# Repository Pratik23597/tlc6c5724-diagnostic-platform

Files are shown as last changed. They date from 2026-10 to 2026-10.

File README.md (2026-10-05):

# Portable Automotive RGB Lighting Diagnostic Platform

**Development and Validation of a Portable Automotive RGB Lighting Diagnostic Platform Using the TLC6C5724-Q1 Automotive LED Driver with Local Control and MQTT-Based Remote Monitoring through Node-RED**

University project, OTH Regensburg (2026) - Pratik Sukare

An ESP32-based test and control unit for the Texas Instruments **TLC6C5724-Q1**, a 24-channel constant-current RGB LED driver for automotive lighting. The platform drives all 24 outputs, runs the driver's built-in diagnostics, and reports faults both on a local TFT display and on a remote Node-RED dashboard over MQTT.

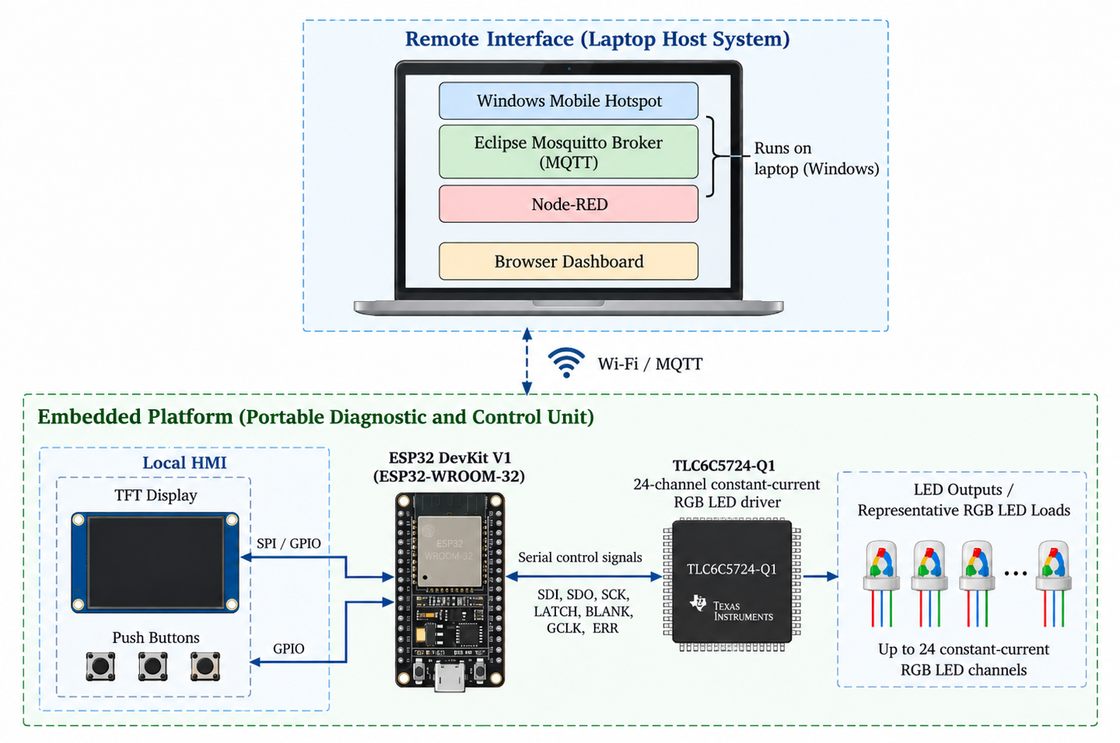
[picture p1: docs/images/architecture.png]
System architecture


## Features

- **Driver interface:** SPI-based serial control of the TLC6C5724-Q1 with separate LATCH, GCLK/BLANK PWM timing and the ERR fault line
- **Diagnostics:** LED open/short (LOD/LSD), short-to-ground, adjacent-pin short (APS), IREF open/short, thermal warning and over-temperature, LOD/LSD self-test, NEG/GCLK integrity test, device status, raw SID readout, error clear
- **Validated under controlled fault conditions:** open and shorted LEDs, short-to-ground, adjacent-pin shorts and IREF faults are detected as expected
- **Non-blocking firmware:** no long delays in the main loop; MQTT commands are queued as pending commands and executed by the main loop; automatic LED tests run as a state machine
- **Six automatic LED tests:** RGB colour cycle, RGB phase rotation, sequential chase, brightness sweep, all white, all off
- **Local HMI:** 128x160 SPI colour TFT and three push buttons - works without any network
- **Remote monitoring:** Eclipse Mosquitto + Node-RED Dashboard 2 with a diagnostics page and a per-channel LED control page (grayscale, dot correction)
- **Network recovery:** retries saved Wi-Fi profiles, and returns to the preferred hotspot if the MQTT broker is unreachable

| Prototype | Node-RED diagnostics |
|---|---|
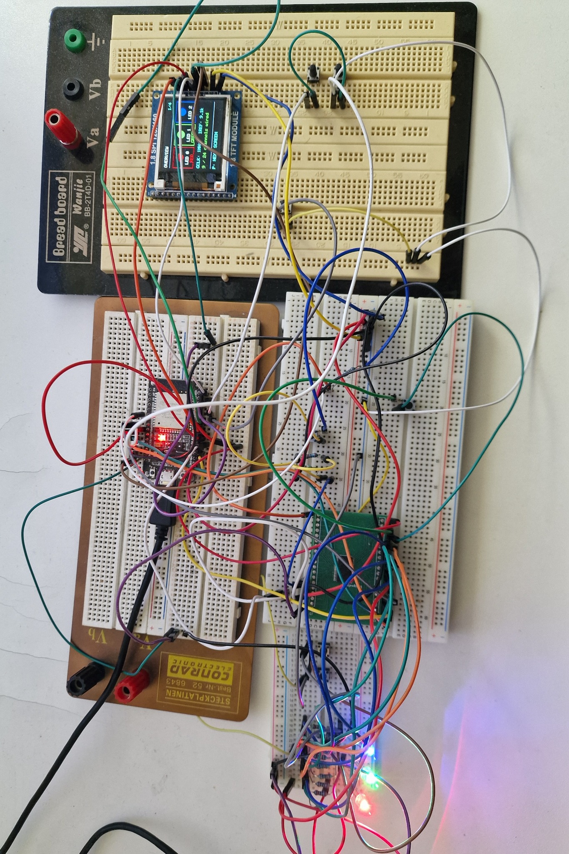
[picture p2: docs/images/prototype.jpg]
Prototype
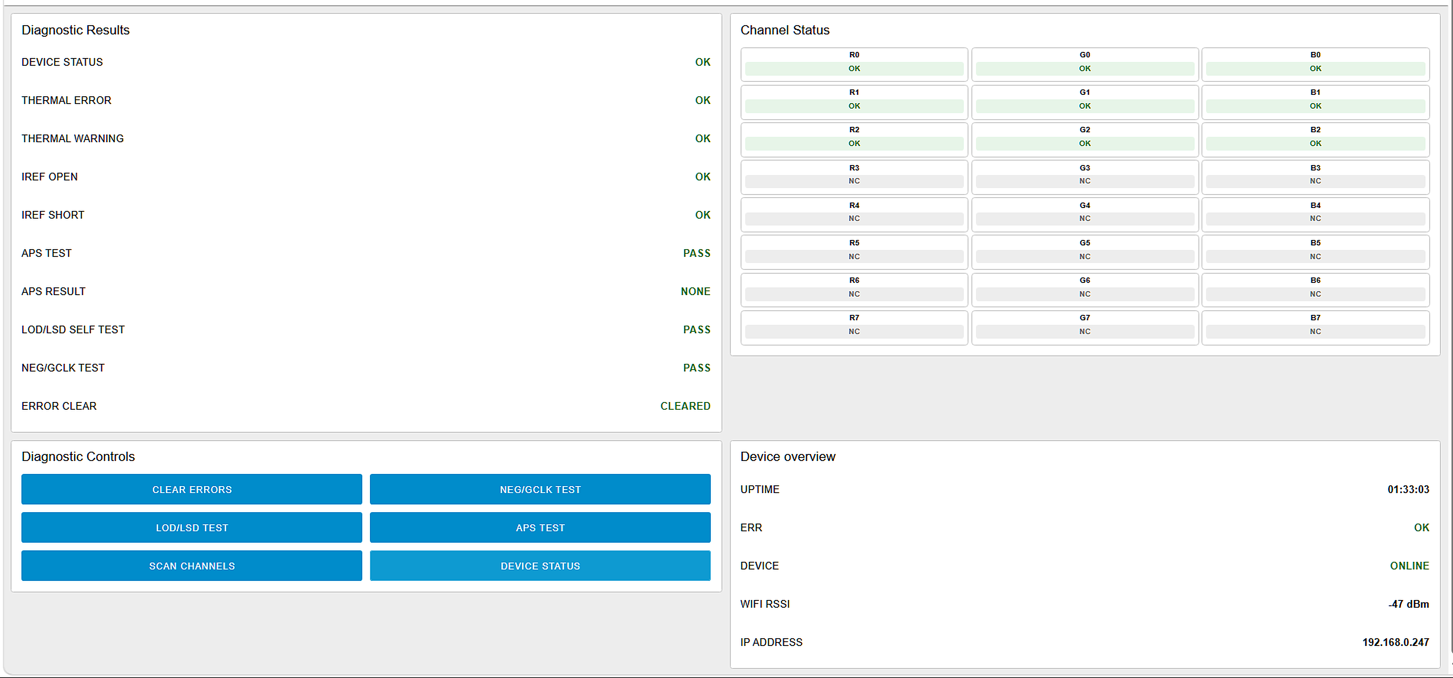
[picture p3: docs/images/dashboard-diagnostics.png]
Diagnostics dashboard
|  |  |

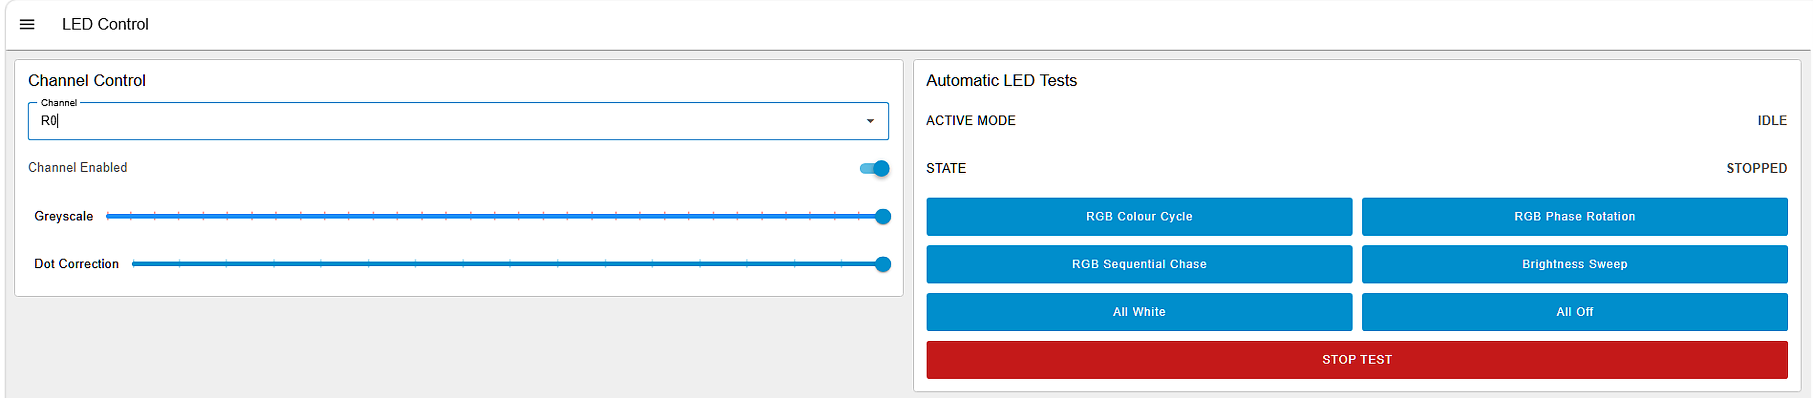
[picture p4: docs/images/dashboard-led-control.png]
LED control page


## Reports

- [Project report](reports/Project_Report.pdf) - design, implementation and results
- [Diagnostic validation report](reports/Diagnostic_Validation_Report.pdf) - test method, fault-injection steps and recorded results for every diagnostic

## Repository layout

| Path | Contents |
|---|---|
| `firmware/TLC6C5724_Diagnostic_Controller/` | ESP32 Arduino sketch, split by module (see below) |
| `node-red/flows.json` | Node-RED Dashboard 2 flow (import via *Menu > Import*) |
| `hardware/` | KiCad schematics (plus a PDF export) of the prototype, and the TLC breakout schematic and PCB layout |
| `mosquitto/` | Mosquitto demo config and a Windows launcher that starts Mosquitto and Node-RED and opens the dashboard |
| `docs/images/` | Architecture, prototype and dashboard figures |
| `reports/` | Project report (paper) and diagnostic validation report with test procedures and results |

Firmware modules:

- `TLC6C5724_Diagnostic_Controller.ino` - declarations and setup / main loop
- `TlcDriver.ino` - TLC frame building, serial transfer, GS/DC/BC configuration
- `Diagnostics.ino` - channel diagnostics, APS, IREF/device status, LOD/LSD, NEG/GCLK, SID debug
- `AutoTests.ino` - automatic RGB / phase / chase / brightness / static tests
- `NetworkMqtt.ino` - Wi-Fi profiles, MQTT commands, status publishing, recovery
- `DisplayUi.ino` - TFT pages and menu navigation
- `Buttons.ino` - push-button input
- `ProjectConfig.h` - MQTT topics, timing constants

## Build

1. Arduino IDE with the **ESP32** board package (board: ESP32 Dev Module).
2. Libraries: **PubSubClient**, **TFT_eSPI** (configure `User_Setup.h` for the 1.8" 128x160 SPI TFT used).
3. Copy `Secrets.example.h` to `Secrets.h` and enter your Wi-Fi and broker settings. `Secrets.h` is git-ignored.
4. On the laptop: install Mosquitto and Node-RED with `@flowfuse/node-red-dashboard`, import `node-red/flows.json`, then run `mosquitto/TLC6C5724_Demo_Start.bat` to start the broker and Node-RED and open the dashboard.

## References

- Texas Instruments, *TLC6C5724-Q1 Automotive 24-Channel, Full Diagnostics, Constant-Current RGB LED Driver*, datasheet
- Eclipse Mosquitto, Node-RED and Node-RED Dashboard 2.0 documentation

## License

MIT - see [LICENSE](LICENSE). Third-party code (e.g. ST HAL/CMSIS drivers, libraries) keeps its own license.

## Author

Pratik Sukare - [LinkedIn](https://www.linkedin.com/in/pratiksukare) | pratiksukare235@gmail.com

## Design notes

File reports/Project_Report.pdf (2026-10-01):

# Development and Validation of a Portable Automotive RGB

# Lighting Diagnostic Platform Using the TLC6C5724-Q1

# Automotive LED Driver with Local Control and MQTT-Based

# Remote Monitoring through Node-RED

Pratik Somnath Sukare

Faculty of Applied Natural Sciences and Cultural Studies

Ostbayerische Technische Hochschule Regensburg

Regensburg, Germany

pratik.sukare@st.oth-regensburg.de

Abstract—A modern automotive lighting solution requires the availability of an LED controller along with the ability to detect faults that can occur. This project presents a portable testing and control device for automotive lighting solutions that employs the Texas Instruments TLC6C5724-Q1, a 24-channel constant-

current RGB LED driver.
An ESP32 microcontroller is used to control the driver,

perform diagnostic tests, operate the RGB LEDs, and provide a local TFT display with buttons for local interaction. The system was tested under normal operating conditions and controlled fault conditions to verify the implemented control and diagnostic functions. The final setup provides a compact and practical

platform for studying LED driver operation, communication, diagnostics, and fault detection.

I. Introduction
Automotive | lighting systems | utilize | multichannel LED

drivers to manage the luminous intensity and color in nu-

merous outputs. In addition to controlling the current and

implementing pulse width modulation, it is necessary for these

drivers to detect electrical and thermal faults that may affect

the functioning of the LED lighting. Integrated diagnostics,

thus, becomes an essential feature of automotive LED control.

The | Texas | Instruments | TLC6C5724-Q1 is | a | 24-channel

constant-current RGB LED driver designed for automotive

applications. This device offers grayscale and current control

via a serial interface; it also provides diagnostic capabilities

to detect open and short LED conditions, adjacent-pin shorts,

reference resistor faults, and thermal issues [1]. This allows

the use of this device not only for LED control but also for

fault detection.

The ESP32 is used to control all 24 output channels, perform

diagnostic procedures, and provide local control via a TFT

display and push buttons. Remote monitoring and control are

provided via the MQTT protocol, with Eclipse Mosquitto as

the broker and Node-RED as the browser-based user interface
[2]–[5].

The system was tested in the conditions of normal operation,

fault introduction | in | a | controlled manner, automatic | LED

tests, and network reconfiguration. As a result, the portable platform providing local and remote control, diagnostics, and

test capabilities for TLC6C5724-Q1 was created.

II. Setup Overview

The structure of the project consists of four layers:

1) TLC6C5724-Q1 LED driver,
2) ESP32 controller,
3) local human-machine interface (TFT), and
4) laptop-based remote interface (Node-Red).

Both the firmware and the dashboard provide access to

the controlling and diagnostic parameters for all 24 output

channels.

## The ESP32 sends the TLC6C5724-Q1 LED driver’s TLC

serial control commands and provides the Grayscale Clock

and Blanking control for PWM functionality. The ERR signal

serves as the fault indicator. A TFT display and three push

buttons provide local navigation, parameter selection, manual

control, and access to diagnostics when the network is unavail-

able.

On | the | remote | side, the | laptop runs | Eclipse | Mosquitto

and Node-RED. The ESP32 connects to the laptop hotspot,

publishes | status | and diagnostic | results, and subscribes | to

command topics. Node-RED uses the same broker to display

device information and send commands back to the ESP32.

A Windows batch launcher starts Mosquitto and Node-RED,

waits until the server is available, and then automatically opens

the diagnostics page.

III. Design and Theory

# A. TLC6C5724-Q1 LED Driver

The TLC6C5724-Q1 is a 24-channel constant-current RGB

LED driver. Each output can sink up to 50mA. The device

provides 7-bit dot correction for individual channels and 8-

bit brightness control for the RGB groups. Grayscale control

can be configured for 12-, 10-, or 8-bit resolution [1]. These

functions support channel adjustment and PWM brightness

control.

The driver also includes several diagnostic functions. These

include LED open and short detection, output short-to-ground

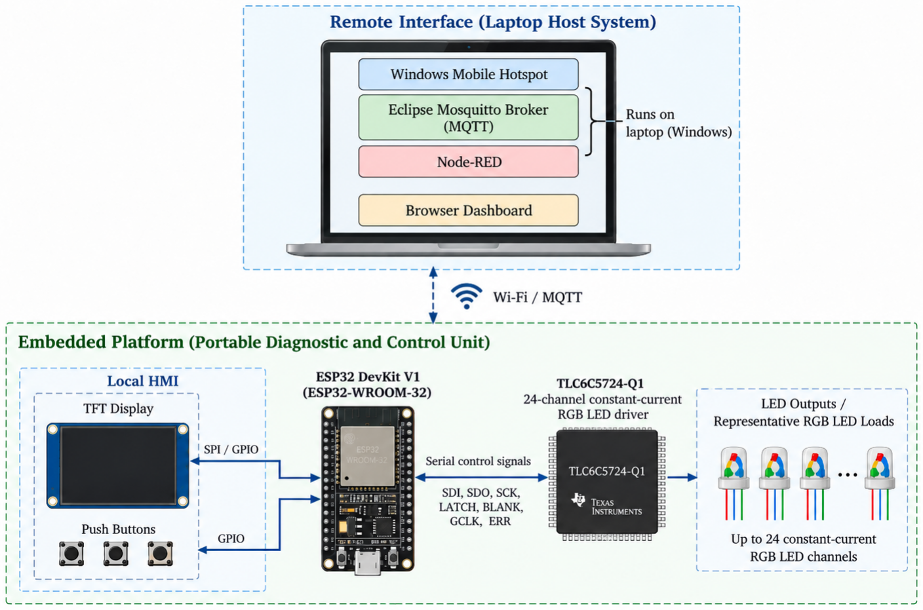
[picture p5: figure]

Fig. 1: System architecture of the portable TLC6C5724-Q1 diagnostic and control platform.

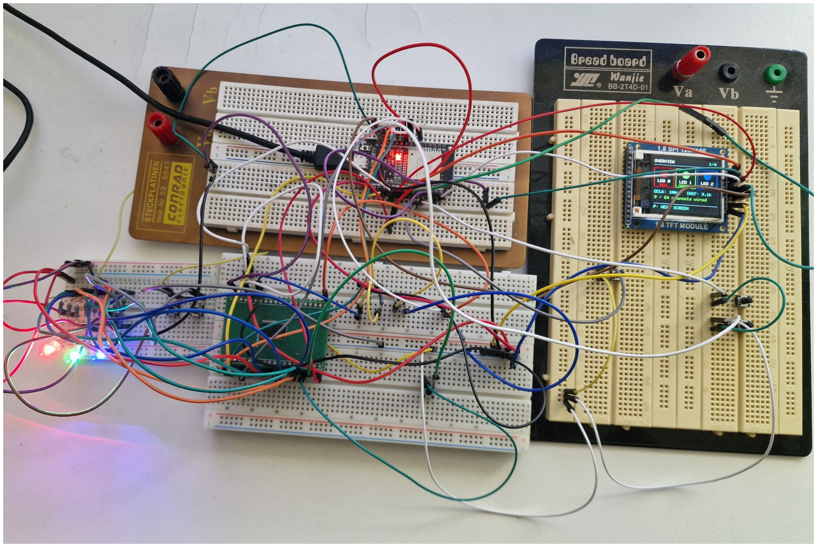
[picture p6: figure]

Fig. | 2: Prototype overview | showing the ESP32 controller,
TLC6C5724-Q1 hardware, | TFT | interface, | push buttons,

wiring, and RGB LED outputs.

detection, adjacent-pin short detection, thermal prewarning

and shutdown, and IREF resistor open and short detection.

It also monitors GCLK and LOD/LSD register integrity and

provides an LOD/LSD circuit self-test [1]. These functions

form the basis of the diagnostic pages on the TFT and Node-

RED dashboard.

# B. ESP32–TLC Hardware Interface

The ESP32 acts as the main controller and network inter-

face. Communication with the TLC6C5724-Q1 uses an SPI

based for control and diagnostic data. Separate signals are

used for latching, PWM timing and fault indication. This keeps the hardware interface simple and separates data transfer from

LED timing and diagnostics.

# C. Firmware Structure and Main Loop

The firmware runs from the main loop and handles each

task in small steps. Long delays are avoided so that LED tests,

button input, diagnostics, Wi-Fi, MQTT, and TFT updates can

all run regularly.

MQTT messages are first checked and stored as pending

commands. The main loop then performs the requested TLC

action. This keeps network handling short and allows the local

controls to respond quickly. Automatic LED tests use a simple

state machine. The current test, step, direction, and elapsed

time decide when the next LED pattern is sent.

# D. Diagnostic Functions

The diagnostic functions implemented in the project are

summarized in Table I [1].

# E. Local TFT and Button Interface

The local interface uses a compact colour 128×160 SPI TFT

and three push buttons. The buttons provide page navigation,

option selection, and execution of the selected function. The

local TFT interface | is | independent of MQTT availability,

allowing the LED-driver hardware to remain controllable if

a wireless connection is unavailable.

# F. Remote Monitoring and Control

The ESP32 connects to the laptop over Wi-Fi. MQTT is

used to | send commands | and receive | status | data | [2], [6].

Mosquitto runs on the laptop and handles the MQTT messages
[7].

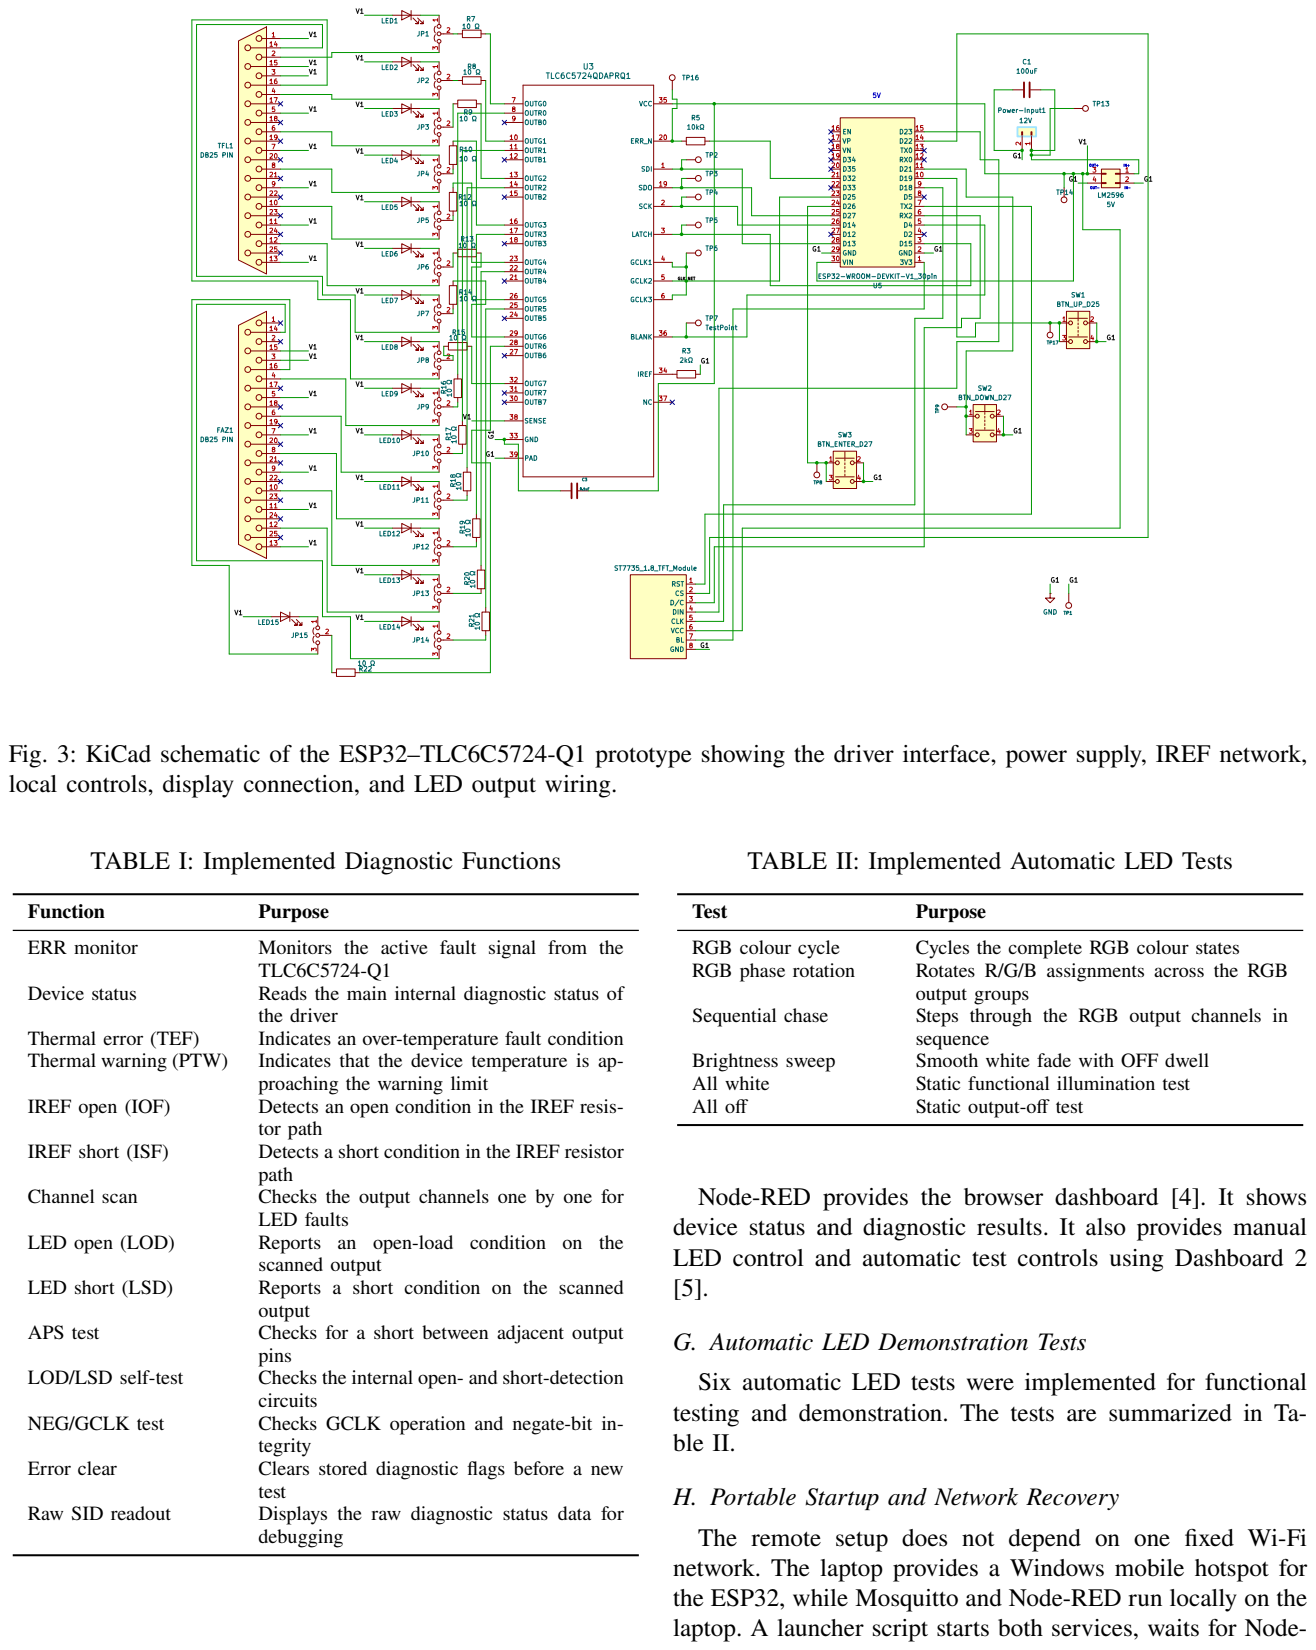
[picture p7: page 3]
Function; Purpose; ERR monitor; Monitors; the; active; fault signal from; TLC6C5724-Q1; Device status; Reads the main internal diagnostic status of; the driver; Thermal error (TEF); Indicates an over-temperature fault condition; Thermal warning (PTW); Indicates that the device temperature is ap-; IREF open (IOF); Detects an open condition in the IREF resis-; tor path; IREF short (ISF); Detects a short condition in the IREF resistor; path; Channel scan; Checks the output channels one by one for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

Fig. 3: KiCad schematic of the ESP32–TLC6C5724-Q1 prototype showing the driver interface, power supply, IREF network,

local controls, display connection, and LED output wiring.

TABLE I: Implemented Diagnostic Functions

TABLE II: Implemented Automatic LED Tests

proaching the warning limit

Node-RED provides the browser dashboard [4]. It shows

device status and diagnostic results. It also provides manual

LED control and automatic test controls using Dashboard 2

G. Automatic LED Demonstration Tests

Six automatic LED tests were implemented for functional

testing and demonstration. The tests are summarized in Ta-
ble II.

H. Portable Startup and Network Recovery

network. The laptop provides a Windows mobile hotspot for

the ESP32, while Mosquitto and Node-RED run locally on the

laptop. A launcher script starts both services, waits for Node-

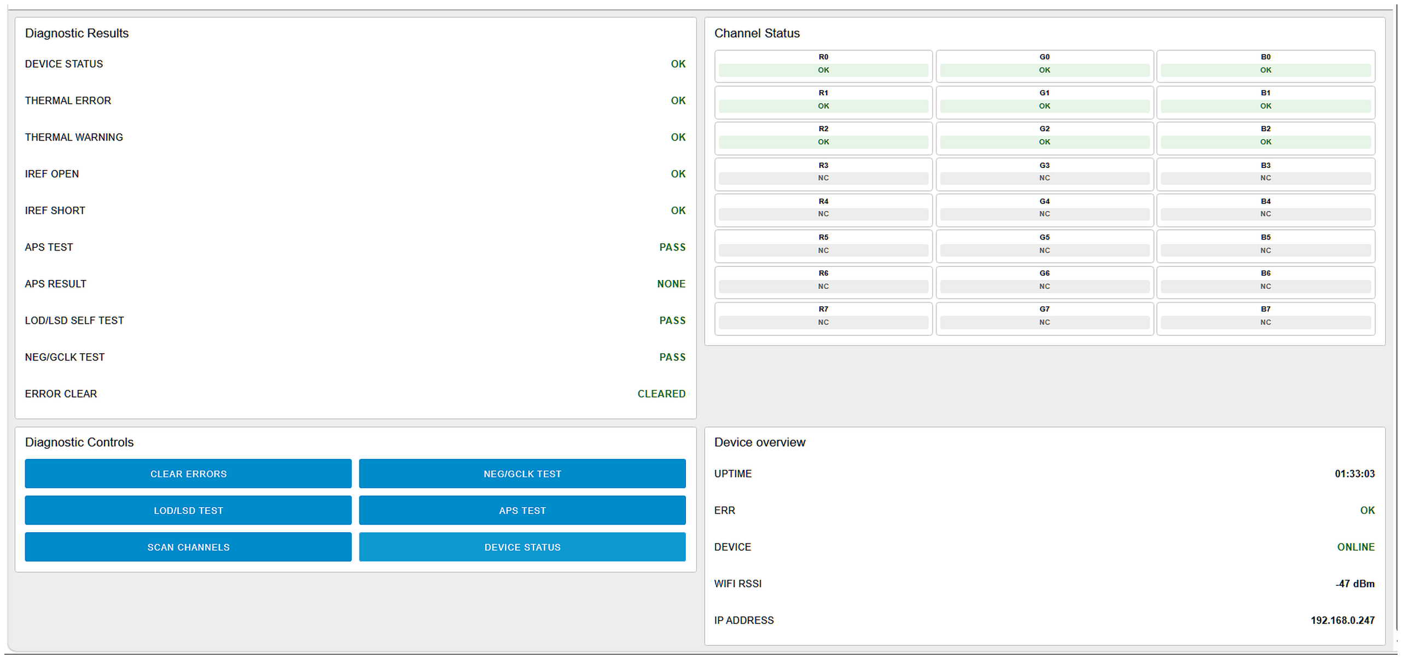
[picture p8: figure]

(a) Diagnostics page showing device status, channel status, diagnostic controls, and device overview.

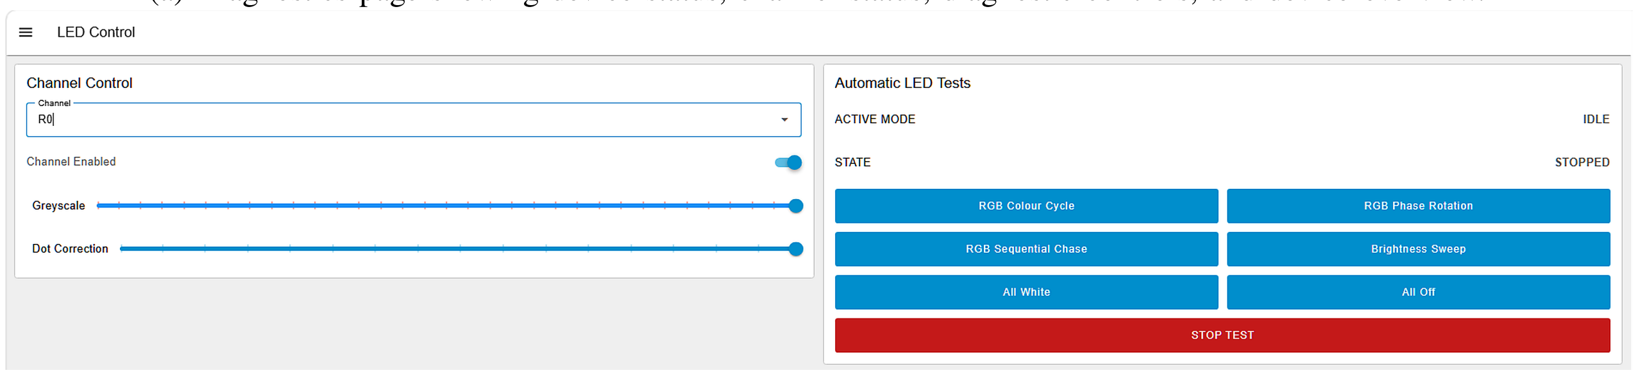
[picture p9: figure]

(b) LED control page for manual channel settings and automatic LED tests.

Fig. 4: Node-RED Dashboard 2 remote monitoring and control interface.

RED to become available, and then opens the diagnostics

dashboard.

The firmware can recover when the network changes. If the

Wi-Fi connection is lost, the ESP32 tries the saved network

profiles again. If Wi-Fi remains connected but the MQTT

broker cannot be reached for a set time, the ESP32 disconnects

and returns to the preferred hotspot [6].

IV. Results

The system was tested under normal operating conditions

and under controlled fault conditions. The diagnostic functions

correctly detected LED open and short conditions, short-to-

ground faults, adjacentpin shorts using APS, and IREF open

and short faults. The device-status check, LOD/LSD self-test,

NEG/GCLK test, and error-clear function also returned the

expected results. Together, these tests confirm that the platform

can identify both channel-level and device-level faults.

Remote control through Node-RED was also verified. Diag-

nostic commands, manual LED control, automatic LED tests,

and device status could be operated from the dashboard. The

launcher and Wi-Fi/MQTT recovery functions also worked as

intended.

V. Conclusion

A portable automotive diagnostic system using the automo-

tive LED driver TLC6C5724-Q1 and ESP32 microcontroller

was designed for automotive lighting solutions. This project

combined LED diagnostics, individual control, group based

control and both local and remote monitoring and control. Sev-

eral fault conditions were tested under controlled conditions

and the diagnostic functions identified the expected faults. The

results were displayed in realtime on both interfaces. The fault

status could also be cleared locally or remotely after the fault

condition was removed. The same setup can support different

automotive lighting applications such as headlights, interior

lighting, rear lighting, ambient lighting and advanced solutions
like window lighting and puddle lighting.

Acknowledgment

I would like to thank Mr. Gerald Schickhuber and Prof.

Johannes Reschke for their guidance, technical feedback, and

support during the development and validation of the project.

References

## [1] TLC6C5724-Q1 Automotive 24-Channel, Full Diagnostics, Constant-

Current RGB LED Driver, Texas Instruments, 2018, datasheet, Rev. A.

### [Online]. Available: https://www.ti.com/lit/ds/symlink/tlc6c5724-q1.pdf

[2] “MQTT Version | 5.0,” OASIS Open, OASIS Standard, Mar. | 2019.
[Online]. | Available: | https://docs.oasis-open.org/mqtt/mqtt/v5.0/mqtt-v5.

### 0.html

[3] Eclipse Mosquitto Project, “Eclipse Mosquitto Documentation,” Online
documentation, | accessed | 2026-09-09. | [Online]. | Available: | https://

mosquitto.org/documentation/

[4] OpenJS Foundation and Contributors, “Node-RED,” Online documenta-

tion, accessed 2026-09-09. [Online]. Available: https://nodered.org/

[5] FlowFuse, | “Node-RED | Dashboard | 2.0 | Documentation,” | Online
documentation, | accessed | 2026-09-09. | [Online]. | Available: | https:

//dashboard.flowfuse.com/getting-started
[6] Espressif Systems, “Arduino ESP32 Wi-Fi API,” Online documentation,
accessed 2026-09-09. | [Online]. | Available: | https://docs.espressif.com/

projects/arduino-esp32/en/latest/api/wifi.html

[7] Eclipse | Mosquitto | Project, | “mosquitto.conf Manual Page,” Online

documentation, accessed 2026-09-09. [Online]. Available: https://www.

mosquitto.org/man/mosquitto-conf-5.html

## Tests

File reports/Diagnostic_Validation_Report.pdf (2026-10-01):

# Diagnostic Validation of a Portable Automotive RGB Lighting Platform Using the TLC6C5724-Q1 Automotive LED Driver

Pratik Somnath Sukare
Faculty of Applied Natural Sciences and Cultural Studies Ostbayerische Technische Hochschule Regensburg Regensburg, Germany
I. INTRODUCTION
This report covers the diagnostic tests carried out on the TLC6C5724-Q1 platform. The tests were run with the ESP32 controller. Both healthy and fault cases were checked. Results were shown on the local TFT and on Node-RED.
The tested functions were ERR status, device status, IREF open and short, channel scan, LED open, LED short, output short-to-ground, APS, LOD/LSD self-test, NEG/GCLK test, and error clear.

II. SYSTEM UNDER TEST
The setup uses an ESP32, a TLC6C5724-Q1 LED driver, a TFT, push buttons, and a laptop. The ESP32 controls the TLC through the serial interface. It also provides GCLK and BLANK.
The TLC ERR pin is connected to the ESP32. ERR is active low. An external pull-up is used.
The grayscale mode is 12-bit. GCLK is about 1 MHz. The firmware can test all 24 output channels.
The laptop runs Mosquitto and Node-RED. MQTT carries commands and status data between the ESP32 and the dashboard.
The TLC6C5724-Q1 is a 24-channel constant-current RGB LED driver. It includes LED-open, LED-short, output short-to-ground, APS, thermal, IREF, NEG, and LOD/LSD test functions [1].

III. DIAGNOSTIC DATA PATH
The TLC returns diagnostic data through SID. SID contains channel fault bits and device status bits [1].
The ESP32 reads SID through SDO. The firmware then checks the required bits. The result is shown on the TFT and Node-RED.
Data path: Fault condition → TLC diagnostic logic → SID or ERR → ESP32 → TFT / MQTT → Node-RED.

TABLE I: Diagnostic fields used in the project

Field | Use
LOD1 / LOD2 | LED open and output short-to-ground
LSD1 / LSD2 | LED short
APS register +
APS_FLAG

Adjacent-pin short result

TEF / PTW | Thermal status
ISF / IOF | IREF short and open status
LOD_LSD_FLAG | LOD/LSD self-test result
NEG1 / NEG2 | NEG/GCLK test

TABLE II: Reference channel-fault patterns

Condition | LOD1 LOD2 LSD1 LSD2 | Result
Healthy | 0 | 0 | 0 | 1 | OK
LED open | 1 | 0 | 0 | 1 | OPEN
LED short | 0 | 0 | 1 | 1 | LED SHORT
Output short-to-GND | 1 | 1 | 0 | 0 | OUT-GND

IV. TEST METHOD
The same basic test flow was used for the physical fault tests.
1) Start with the system in the healthy state.
2) Record the normal result.
3) Power off before changing the test wiring.
4) Apply the test condition.
5) Run the related diagnostic.
6) Check the result.
7) Remove the test condition.
8) Restore the normal wiring.
9) Clear stored errors when needed.
10) Check the healthy state again.
V. DIAGNOSTIC TESTS
A. Reference Fault Patterns
Table II shows the bit patterns used by the channel scan. These patterns match the TLC diagnostic data [1].
B. ERR Monitor
Test goal. Check the ERR signal in normal and fault states. How it works. ERR is active low and open drain. The ESP32 reads the pin and sends the state to Node-RED [1]. Test steps.
1) Start with the normal setup.

TABLE III: Global SID status fields

Status | SID bit(s) Normal | Fault
TEF | 215 | 0 | 1
PTW | 214 | 0 | 1
APS_FLAG | 213..211 | 011 | 110
ISF | 210 | 0 | 1
IOF | 209 | 0 | 1
LOD_LSD_FLAG | 208..206 | 011 | 110
NEG1 / NEG2 | 205 / 204 | 0 / 0 | Toggle

TABLE IV: Special diagnostic commands

Command | Code | Use
ERROR Clear | 0xA53 | Clears stored error and APS status
APS check | 0x53A | Runs the APS test
LOD/LSD | self-
test
0x535 | Checks the LOD/LSD circuits
Negate Bit Toggle | 0x55A | Toggles NEG bits
2) Check that ERR is high.
3) Run Device Status.
4) Apply an IREF fault.
5) Check that ERR goes low.
6) Remove the fault.
7) Clear the error.
8) Check that ERR returns high.
Expected. ERR is HIGH in the healthy state. ERR is LOW when the fault is active.
Result. ERR changed as expected.

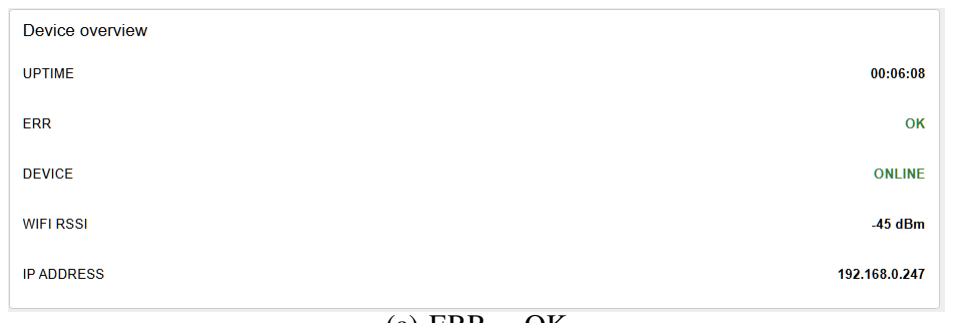
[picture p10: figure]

(a) ERR = OK

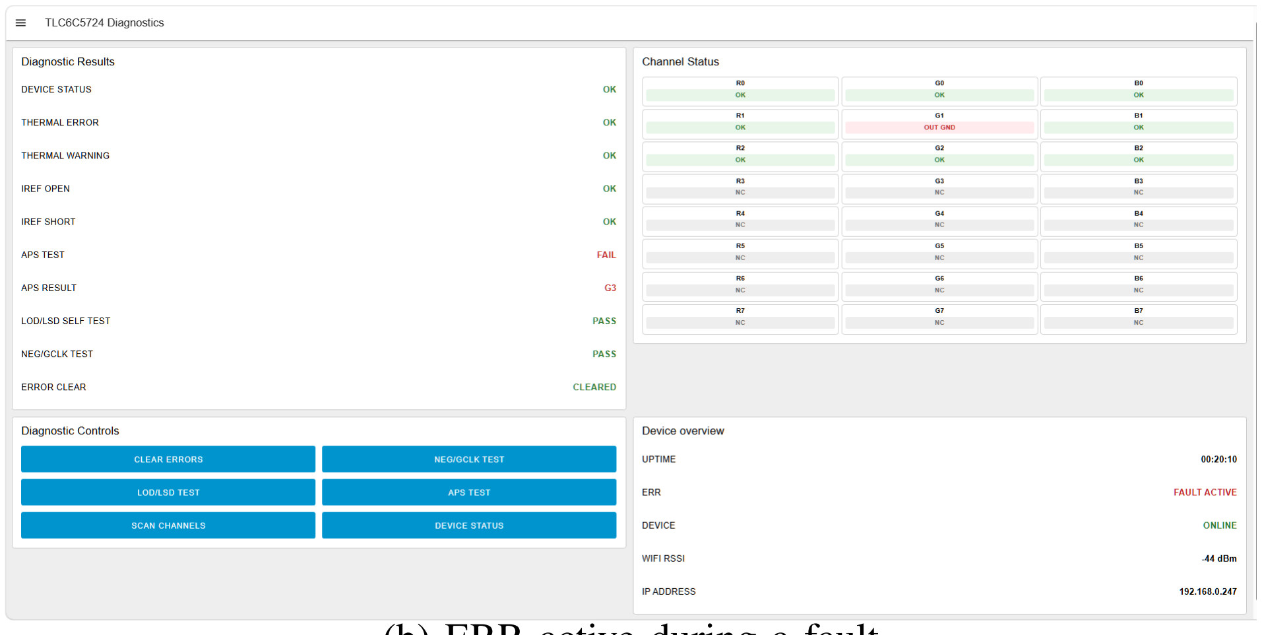
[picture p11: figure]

(b) ERR active during a fault

Fig. 1: ERR status in healthy and fault states.

C. Device Status
Test goal. Check TEF, PTW, ISF, and IOF.
How it works. TEF is SID bit 215. PTW is bit 214. ISF is bit 210. IOF is bit 209 [1].
Test steps.
1) Run Device Status in the healthy state.
2) Record TEF, PTW, ISF, and IOF.
3) Run the IREF open test.
4) Run the IREF short test.
5) Check the matching status bit.
6) Restore the IREF path.
7) Clear the error.
Expected. TEF, PTW, ISF, and IOF are 0 in the healthy state.
Result. The healthy status was correct. The IREF tests also set the correct status bit. TEF and PTW stayed clear during normal operation.

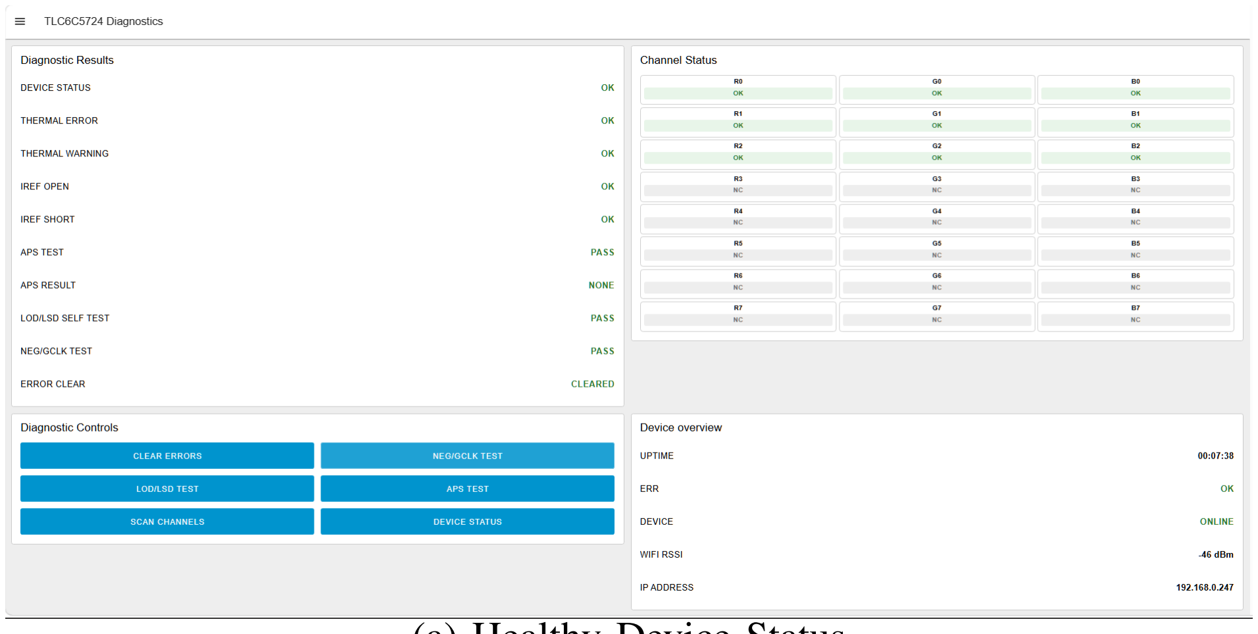
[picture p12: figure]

(a) Healthy Device Status

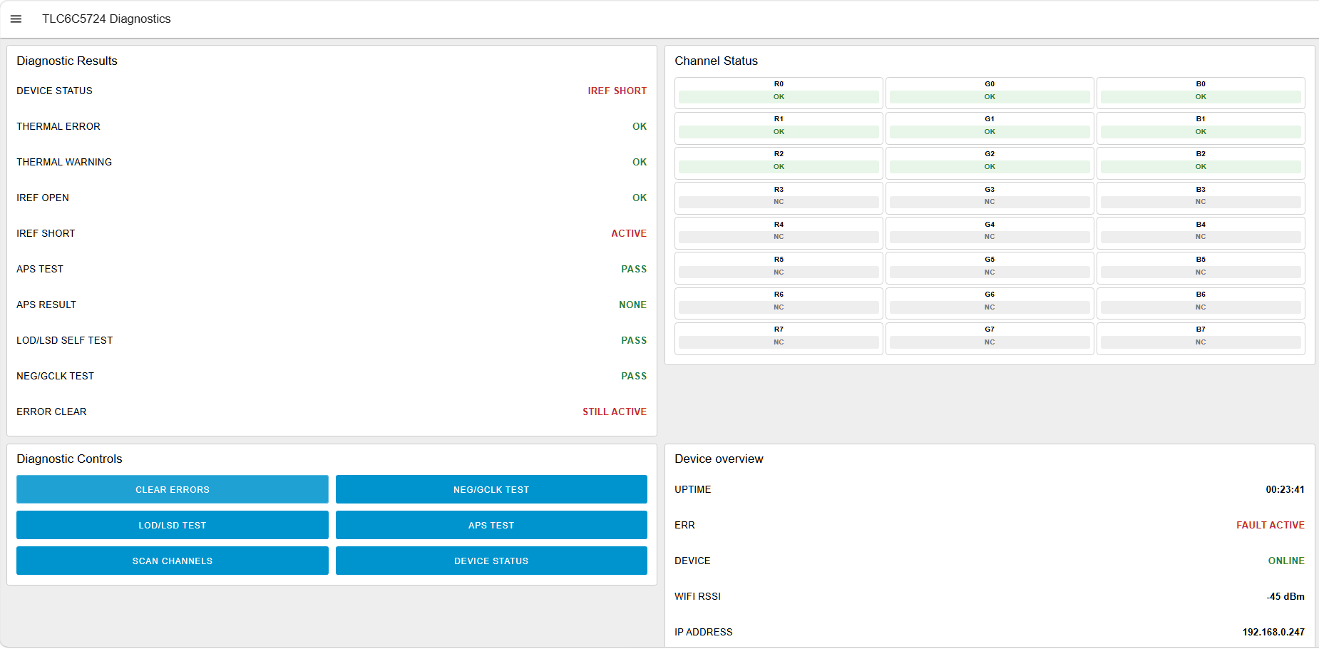
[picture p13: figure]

(b) Device Status during IREF short

Fig. 2: Device status in healthy and IREF-fault states.

D. Sequential Channel Scan
Test goal. Check the output channels one at a time.
How it works. The firmware tests one output and reads LOD1, LOD2, LSD1, and LSD2. It then assigns the channel state.
Test steps.
1) Run the scan in the healthy state.
2) Check that the active outputs show OK.
3) Apply one channel fault.
4) Run the scan again.
5) Check the affected channel.
6) Remove the fault.
7) Run the scan once more.
Expected. The fault should appear on the affected channel only.
Result. OPEN, LED SHORT, and OUT-GND were detected as separate states.

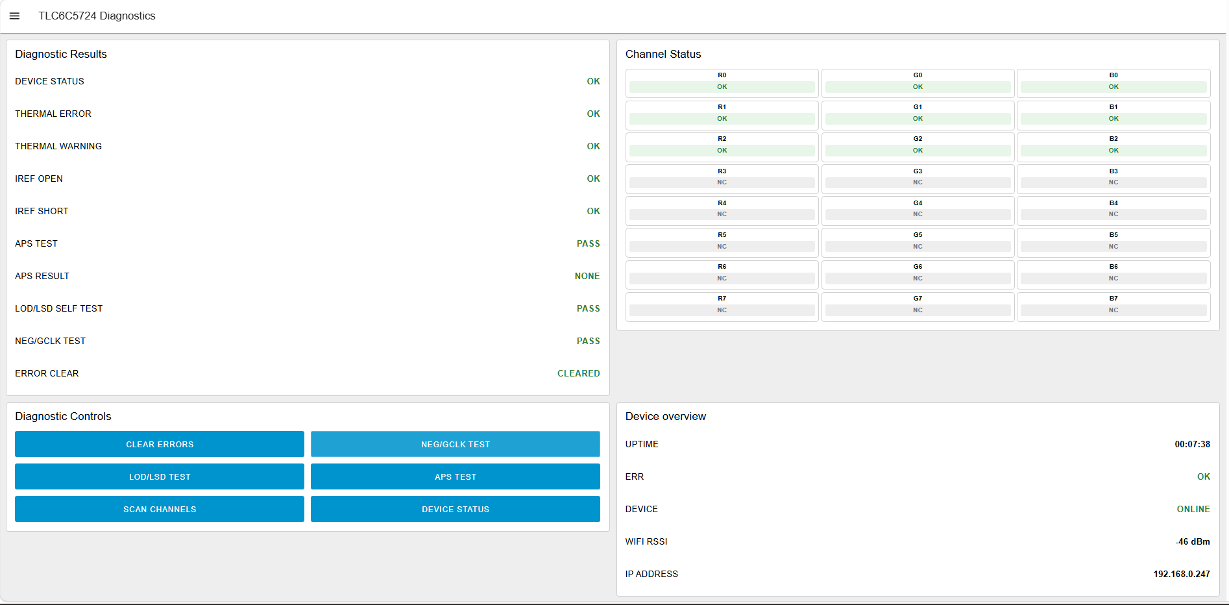
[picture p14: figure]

(a) Healthy channel scan

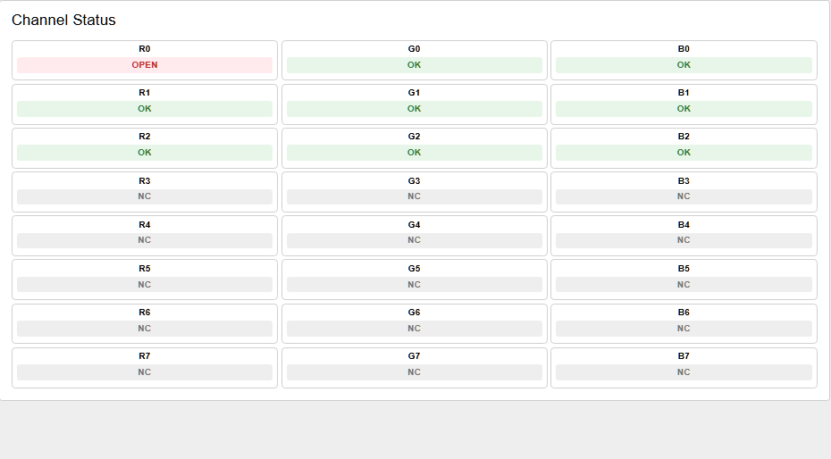
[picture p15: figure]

(b) Channel scan with R0 OPEN

Fig. 3: Channel scan in healthy and fault states.

E. LED Open Test
Test goal. Check LED-open detection on one output.
How it works. The TLC checks the output voltage against the LOD threshold [1].
Test steps.
1) Power off the board.
2) Open the selected LED path.
3) Power the board.
4) Run Scan Channels.
5) Check Device Status.
6) Power off the board.
7) Restore the LED path.
8) Run the scan again.
Expected. The selected output should show OPEN. IREF OPEN should stay inactive.
Result. R0 showed OPEN. The other active outputs stayed normal.

TLC6C5724-Q1 OUTx

RLED

LED

VLED

Fig. 4: Sample LED-open test circuit. The switch opens the selected LED path.

(a) Node-RED showing R0 OPEN

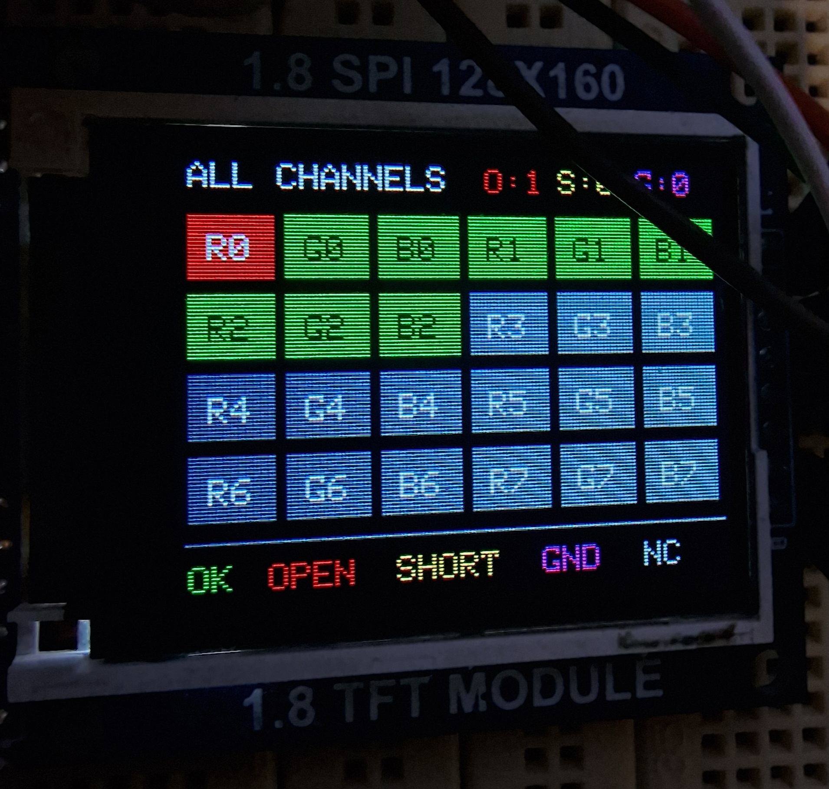
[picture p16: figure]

(b) TFT showing R0 OPEN

Fig. 5: LED-open test result.

F. LED Short Test
Test goal. Check LED-short detection on one output.
How it works. The LSD circuit detects the LED-short condition [1].
Test steps.
1) Start with the healthy setup.
2) Apply the LED-short test condition.
3) Run Scan Channels.
4) Check the selected output.
5) Remove the test condition.
6) Run the scan again.
Expected. The selected output should show LED SHORT. Result. B2 showed SHORT on the channel display.

TLC6C5724-Q1 OUTx RLED

LED

VLED

Fig. 6: Sample LED-short test circuit. The switch bypasses the selected LED.

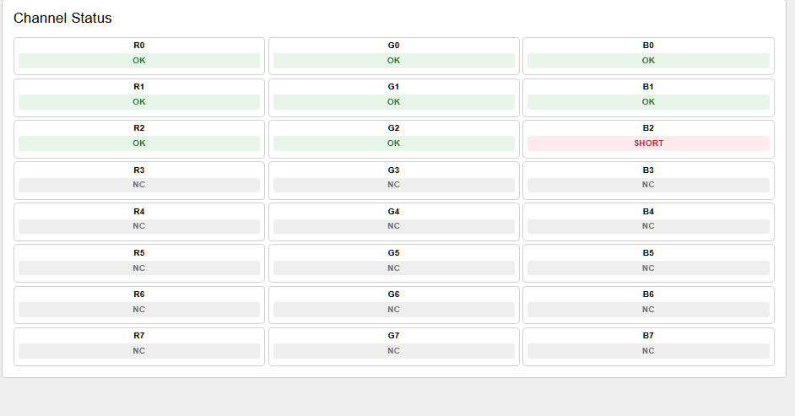
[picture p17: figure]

(a) Node-RED showing B2 SHORT

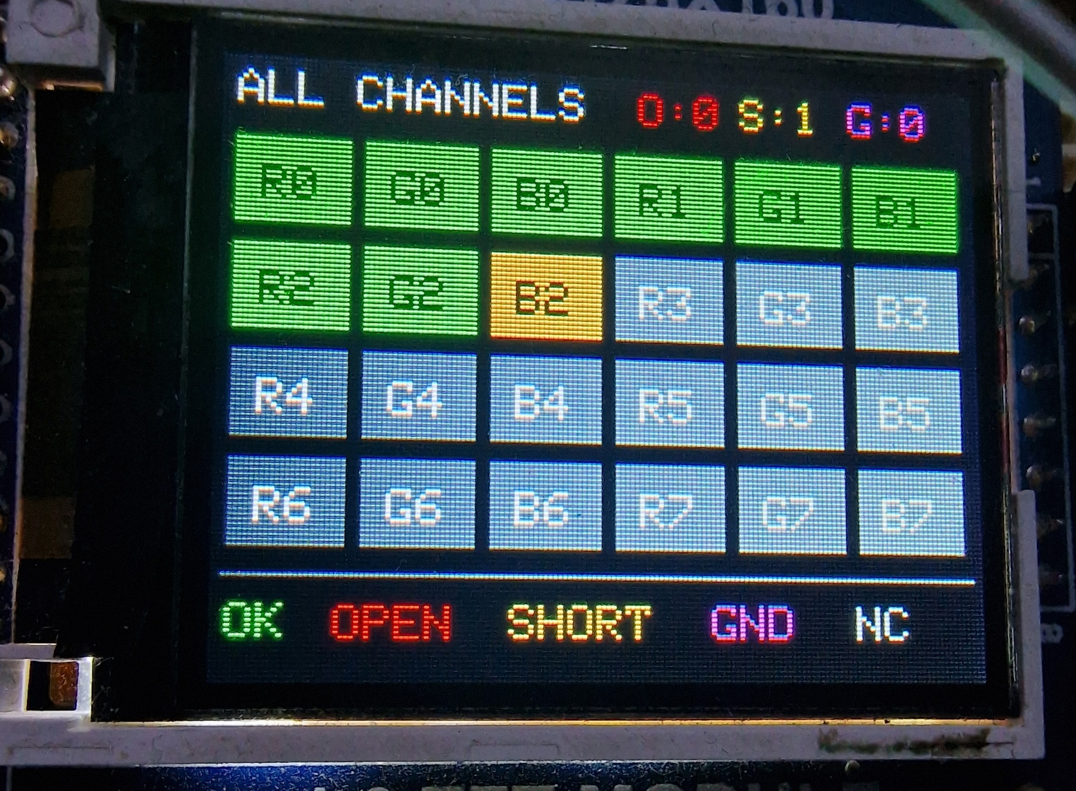
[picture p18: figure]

(b) TFT showing B2 SHORT

Fig. 7: LED-short test result.

G. Output Short-to-Ground Test
Test goal. Check the output short-to-ground case.
How it works. The TLC uses a separate LOD/LSD pattern for this fault [1].
Test steps.
1) Power off the board.
2) Apply the output-to-ground test condition.
3) Power the board.
4) Run Scan Channels.
5) Check the selected output.
6) Remove the test condition.
7) Restore the normal setup.
Expected. The selected output should show OUT-GND. Result. G1 showed OUT GND.

TLC6C5724-Q1 OUTx RLED

LED

VLED

Fig. 8: Sample output-to-ground test circuit. The switch applies the test condition to the selected output.

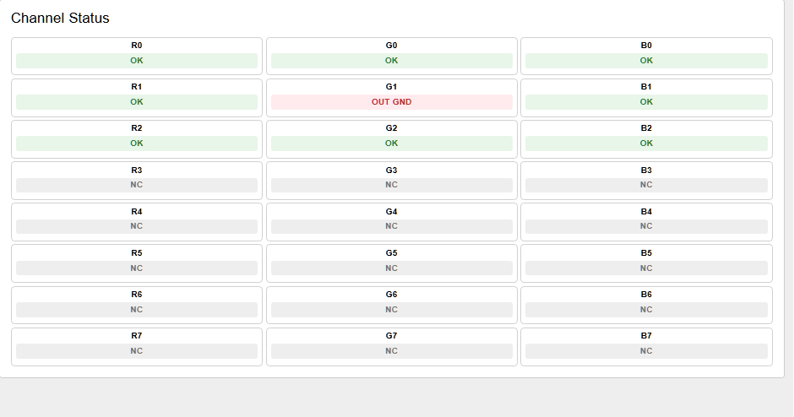
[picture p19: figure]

(a) Node-RED showing G1 OUT GND


(b) TFT showing the G1 ground fault

Fig. 9: Output short-to-ground test result.

H. Adjacent-Pin Short Test
Test goal. Check the APS function.
How it works. APS checks for a short between nearby output pins. APS_FLAG = 011b means pass. APS_FLAG = 110b means fail [1].
Test steps.
1) Run APS in the healthy state.
2) Record PASS.
3) Power off the board.
4) Apply the adjacent-pin test condition.
5) Power the board.
6) Run APS again.
7) Record the result.
8) Remove the test condition.
9) Clear the error.
10) Run APS again.
Expected. The healthy state should show PASS. The fault state should show FAIL and the affected output.
Result. APS passed in the healthy state. It failed during the test condition. G3 was shown as the affected result.

TLC6C5724-Q1

OUTn

RLED

LED

VLED

OUTn+1RLED LED VLED

Fig. 10: Sample APS test circuit. The switch links two neighbouring output nodes.


(a) Node-RED showing APS FAIL


(b) TFT showing APS SHORT G3

Fig. 11: APS test result.

APS sequence: All outputs off → ERROR Clear 0xA53 → APS 0x53A → read SID → check APS result → restore normal output state.

I. IREF Open Test
Test goal. Check the IREF-open function.
How it works. IOF is set when the IREF current falls into the open range [1].
Test steps.
1) Record the healthy Device Status.
2) Power off the board.
3) Open the IREF path.
4) Power the board.
5) Run Device Status.
6) Check IOF and ERR.
7) Power off the board.
8) Restore the IREF path.
9) Power the board.
10) Clear the error.
Expected. IOF should be 1. ISF should be 0. Result. Node-RED and the TFT showed IREF OPEN.

TLC6C5724-Q1 IREF

RIREF

Fig. 12: Sample IREF-open test circuit. The switch opens the referenceresistor path.


(a) Node-RED showing IREF OPEN


(b) TFT showing IREF OPEN

Fig. 13: IREF-open test result.

J. IREF Short Test
Test goal. Check the IREF-short function.
How it works. ISF is set when the IREF current reaches the short range [1].
Test steps.
1) Start with the healthy IREF path.
2) Power off the board.
3) Apply the IREF-short test condition.
4) Power the board.
5) Run Device Status.
6) Check ISF and ERR.
7) Power off the board.
8) Restore the IREF path.
9) Power the board.
10) Clear the error.
Expected. ISF should be 1. IOF should be 0.
Result. Node-RED and the TFT showed IREF SHORT.

TLC6C5724-Q1 IREF

RIREF

Fig. 14: Sample IREF-short test circuit. The switch applies the IREF short test condition.


(a) Node-RED showing IREF SHORT


(b) TFT showing IREF SHORT

Fig. 15: IREF-short test result.

K. LOD/LSD Self-Test

Test goal. Check the internal LED-open and LED-short detection circuits.
How it works. LOD_LSD_FLAG = 011b means pass. LOD_LSD_FLAG = 110b means fail [1].
Test steps.
1) Hold BLANK low.
2) Send 0x535.
3) Read SID.
4) Check bits 208..206.
5) Restore the normal LED state.
Expected. The test should return PASS. Result. The LOD/LSD self-test returned PASS.


Fig. 16: LOD/LSD self-test result.

L. NEG/GCLK Test

Test goal. Check the NEG bits and GCLK-related register change.

How it works. NEG1 and NEG2 toggle after command 0x55A. The related LOD/LSD data changes with the toggle [1].
Test steps.
1) Apply the all-off diagnostic frame.
2) Read the first SID value.
3) Send 0x55A.
4) Read SID again.
5) Check NEG1 and NEG2.
6) Check the LOD/LSD change.
7) Send 0x55A again.
8) Check that the first state returns.
Expected. The NEG bits should toggle. The related data should change. The second command should restore the first state.
Result. The NEG/GCLK test returned PASS.

Fig. 17: NEG/GCLK test result.

M. Error Clear

Test goal. Clear stored diagnostic status before the next test. How it works. ERROR Clear uses command 0xA53. It clears stored error and APS status [1].
Test steps.
1) Run a test that sets a stored status.
2) Restore the healthy setup.
3) Send Error Clear.
4) Run Device Status or APS again.
5) Check that the stored status is cleared.
Expected. ERROR CLEAR should show CLEARED. Result. The stored status cleared correctly.


Fig. 18: Error-clear result.

TABLE V: Dashboard sections

Section | Use
Diagnostic Results | Shows device and built-in test results
Channel Status | Shows OK, OPEN, SHORT, and OUT-GND
Diagnostic Controls | Runs the diagnostic tests
Device Overview | Shows device state, ERR, network data, and
| uptime

VI. NODE-RED DIAGNOSTIC DISPLAY

Node-RED shows the diagnostic results from the ESP32. It also provides the test buttons.
Command topic: tlc6c5724/device01/command Status topics: tlc6c5724/device01/#


(a) Dashboard after startup


(b) Dashboard after the diagnostic checks

Fig. 19: Node-RED diagnostic display.

VII. VALIDATION SUMMARY

TABLE VI: Diagnostic Validation Summary

Test | Result | Status
ERR monitor | ERR changed between healthy and active fault states Verified
Device status | TEF, PTW, ISF, and IOF were read correctly | Verified
LED open | Selected output showed OPEN | PASS
LED short | Selected output showed LED SHORT | PASS
Output | short-to-
GND | Selected output showed OUT-GND | PASS
APS | Adjacent-pin fault was detected | PASS
IREF open | IREF OPEN was detected | PASS
IREF short | IREF SHORT was detected | PASS
LOD/LSD | self-
test | Test returned PASS | PASS
NEG/GCLK | Test returned PASS | PASS
Error clear | Stored status was cleared | PASS
TEF/PTW | Both stayed clear in normal operation | Healthy

VIII. RESULTS
The channel scan detected LED open, LED short, and output short-to-ground as different fault types. APS also detected the adjacent-pin test condition.
The IREF tests worked as expected. IREF open set IOF. IREF short set ISF.
The LOD/LSD self-test returned PASS. The NEG/GCLK test also returned PASS. Error Clear removed the stored status after each test.
The same results were visible on the TFT and Node-RED.

IX. CONCLUSION
The TLC6C5724-Q1 diagnostics were tested with the ESP32 platform. The system detected the tested channel faults and device faults.
LED open, LED short, output short-to-ground, APS, IREF open, and IREF short were tested. The built-in LOD/LSD and NEG/GCLK checks also passed. Error Clear worked after the test conditions were removed.
The setup provides local and remote diagnostic testing for all 24 output channels.

REFERENCES

[1] Texas Instruments, TLC6C5724-Q1 Automotive 24-Channel, Full Diagnostics, Constant-Current RGB LED Driver, rev. a ed., Texas Instruments, Aug. 2018.

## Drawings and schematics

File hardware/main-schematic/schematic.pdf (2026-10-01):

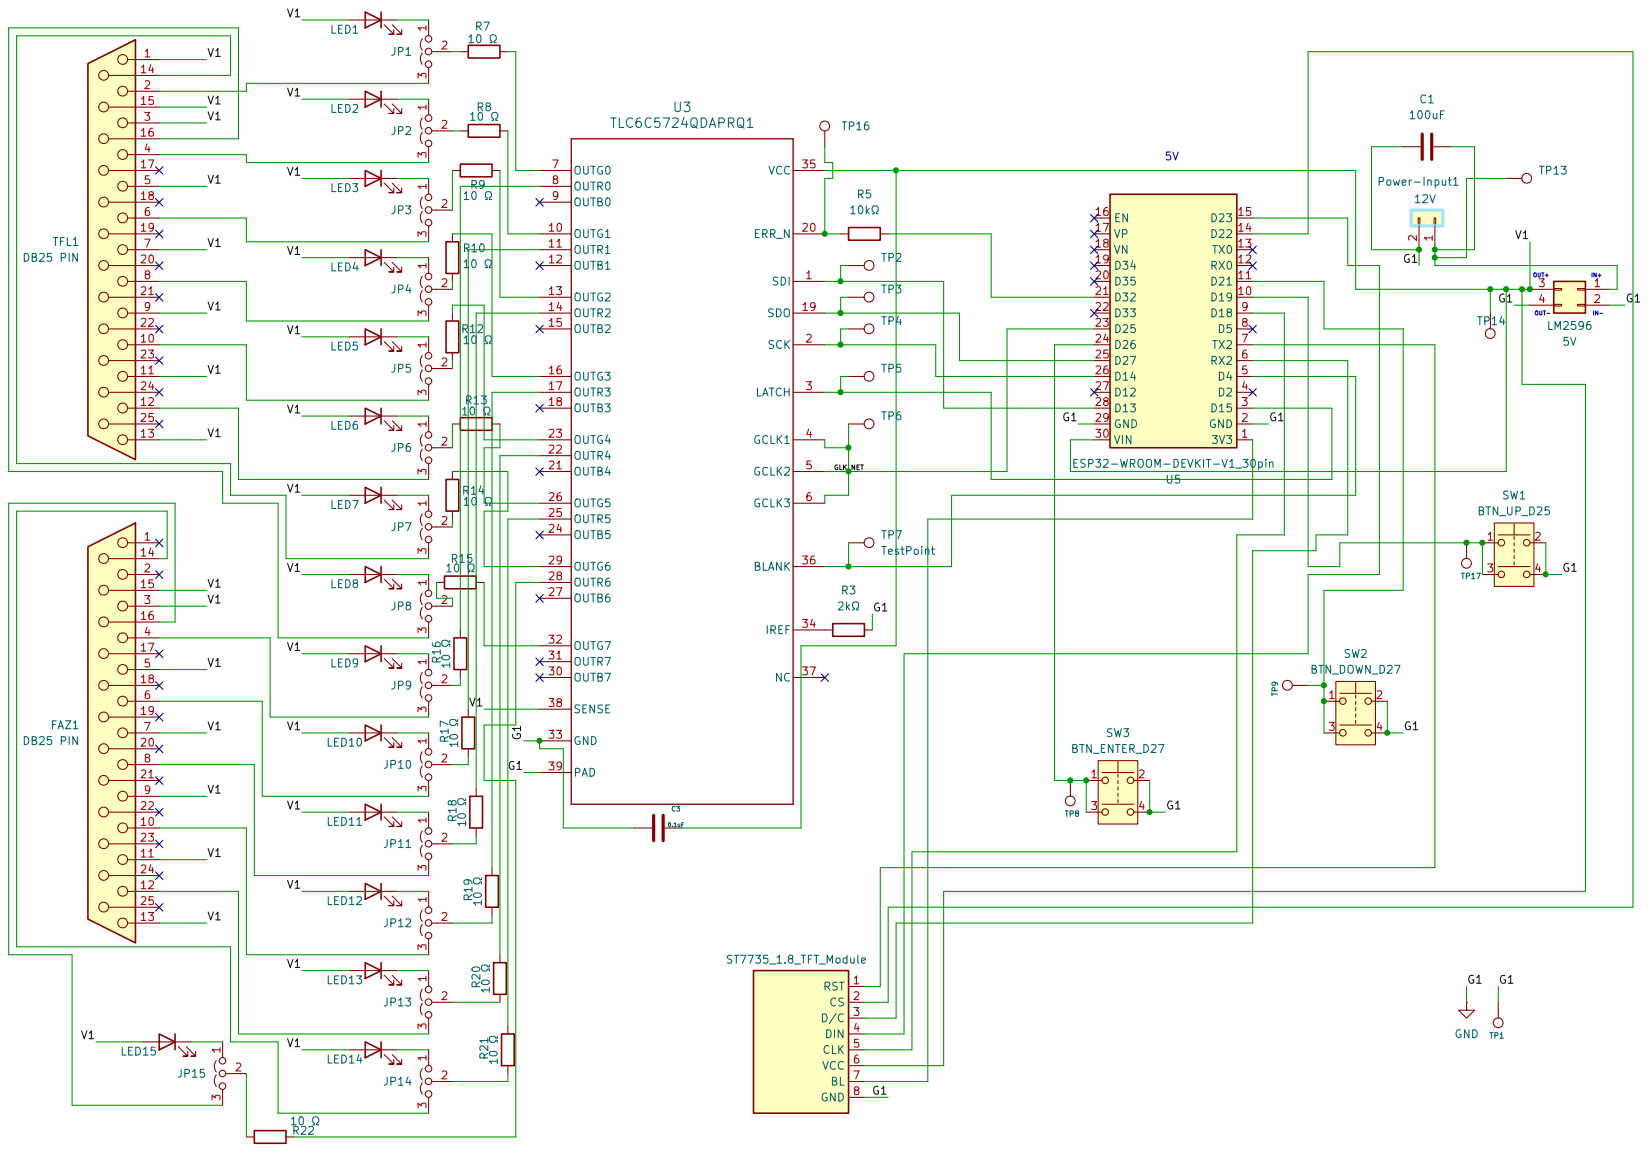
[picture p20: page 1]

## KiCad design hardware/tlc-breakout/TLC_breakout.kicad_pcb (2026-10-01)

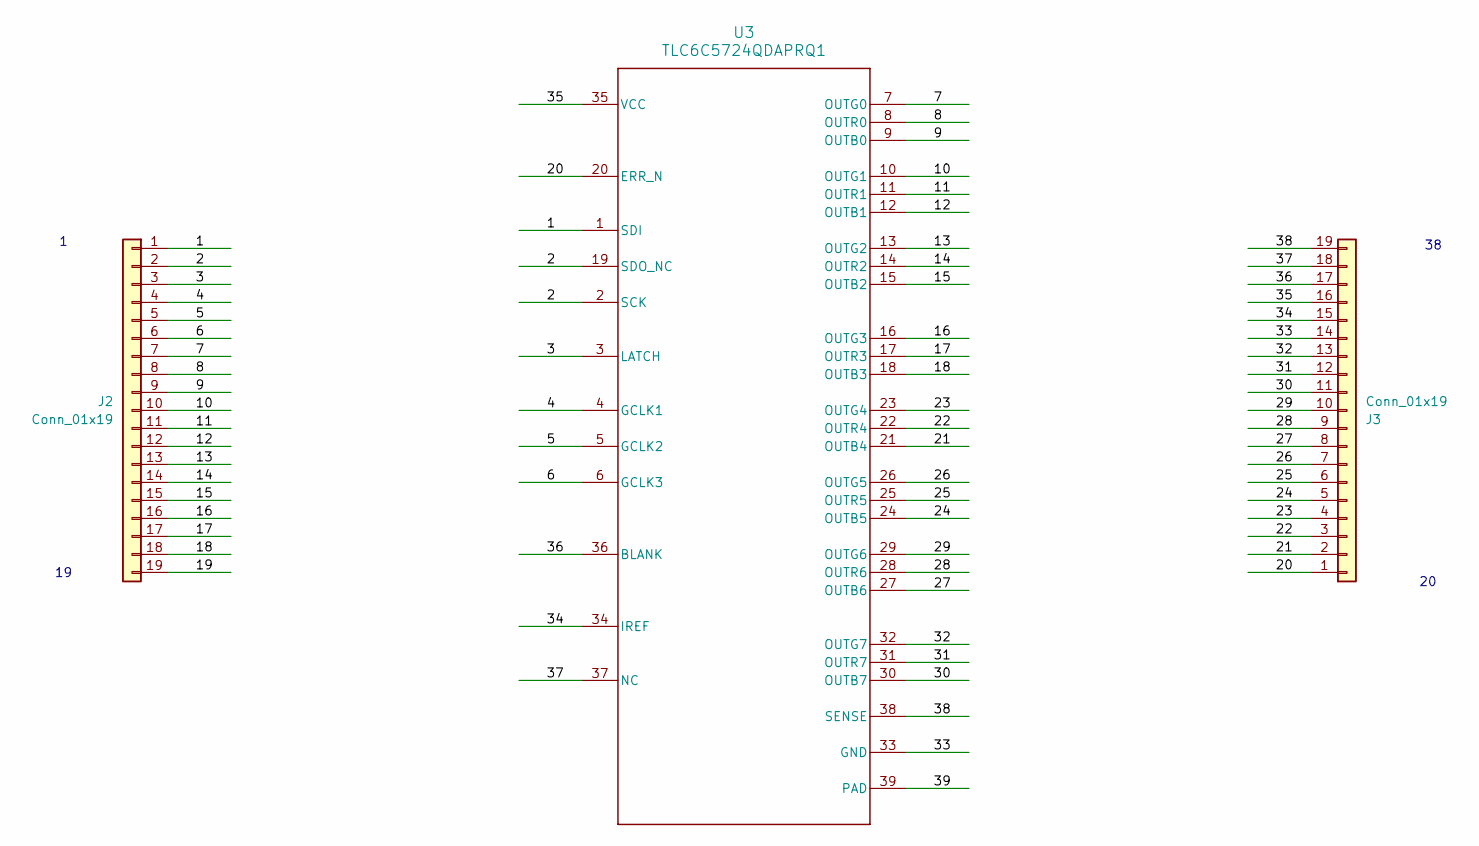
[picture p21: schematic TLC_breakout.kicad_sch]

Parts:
J2, J3: Conn_01x19; PinHeader_1x19_P2.54mm_Vertical
U3: TLC6C5724QDAPRQ1; DAP0038E

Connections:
/1: J2.1, U3.1 (SDI)
/2: J2.2, U3.2 (SCK), U3.19 (SDO_NC)
/3: J2.3, U3.3 (LATCH)
/4: J2.4, U3.4 (GCLK1)
/5: J2.5, U3.5 (GCLK2)
/6: J2.6, U3.6 (GCLK3)
/7: J2.7, U3.7 (OUTG0)
/8: J2.8, U3.8 (OUTR0)
/9: J2.9, U3.9 (OUTB0)
/10: J2.10, U3.10 (OUTG1)
/11: J2.11, U3.11 (OUTR1)
/12: J2.12, U3.12 (OUTB1)
/13: J2.13, U3.13 (OUTG2)
/14: J2.14, U3.14 (OUTR2)
/15: J2.15, U3.15 (OUTB2)
/16: J2.16, U3.16 (OUTG3)
/17: J2.17, U3.17 (OUTR3)
/18: J2.18, U3.18 (OUTB3)
/19: J2.19
/20: J3.1, U3.20 (ERR_N)
/21: J3.2, U3.21 (OUTB4)
/22: J3.3, U3.22 (OUTR4)
/23: J3.4, U3.23 (OUTG4)
/24: J3.5, U3.24 (OUTB5)
/25: J3.6, U3.25 (OUTR5)
/26: J3.7, U3.26 (OUTG5)
/27: J3.8, U3.27 (OUTB6)
/28: J3.9, U3.28 (OUTR6)
/29: J3.10, U3.29 (OUTG6)
/30: J3.11, U3.30 (OUTB7)
/31: J3.12, U3.31 (OUTR7)
/32: J3.13, U3.32 (OUTG7)
/33: J3.14, U3.33 (GND)
/34: J3.15, U3.34 (IREF)
/35: J3.16, U3.35 (VCC)
/36: J3.17, U3.36 (BLANK)
/37: J3.18, U3.37 (NC)
/38: J3.19, U3.38 (SENSE)
/39: U3.39 (PAD)

Board: 2 copper layers, 3 parts (0 on the bottom side), 37 nets, no tracks yet.

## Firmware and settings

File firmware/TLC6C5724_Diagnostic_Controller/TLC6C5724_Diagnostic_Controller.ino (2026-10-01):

#include <Arduino.h>
#include <string.h>
#include <ctype.h>
#include <WiFi.h>
#include <PubSubClient.h>
#include <TFT_eSPI.h>

#include "ProjectConfig.h"



WiFiClient mqttNetworkClient;
PubSubClient mqttClient(mqttNetworkClient);
uint32_t previousWifiAttemptTime = 0;
uint32_t previousMqttAttemptTime = 0;
uint32_t previousMqttHeartbeatTime = 0;

bool wifiBeginIssued = false;
bool wifiTryingPrimaryProfile = true;
bool mqttErrPublishPending = true;

bool mqttChannelScanPublishPending = false;
bool mqttApsPublishPending = false;
bool mqttDeviceStatusPublishPending = false;
bool mqttLodLsdPublishPending = false;
bool mqttNegGclkPublishPending = false;
bool mqttErrorClearPublishPending = false;
bool mqttChannelControlPublishPending = false;
bool mqttAutomaticTestPublishPending = false;

uint8_t mqttChannelControlIndex = 0;

char mqttAutomaticTestName[32] = "none";
char mqttAutomaticTestState[16] = "stopped";

// Last Error Clear result used for MQTT status.
bool mqttErrorClearSucceeded = false;
bool mqttErrorClearErrActive = false;
bool mqttErrorClearTef = false;
bool mqttErrorClearPtw = false;
bool mqttErrorClearIsf = false;
bool mqttErrorClearIof = false;

// NEG/GCLK summary retained for MQTT publishing.
uint16_t mqttNegConnectedExpected = 0;
uint16_t mqttNegConnectedRestoreMatches = 0;
uint16_t mqttNegAllRestoreMatches = 0;

// MQTT remote-command state

enum RemoteCommand : uint8_t {
  REMOTE_COMMAND_NONE = 0,
  REMOTE_COMMAND_DEVICE_STATUS,
  REMOTE_COMMAND_CHANNEL_SCAN,
  REMOTE_COMMAND_APS,
  REMOTE_COMMAND_LOD_LSD,
  REMOTE_COMMAND_NEG_GCLK,
  REMOTE_COMMAND_CLEAR_ERRORS,
  REMOTE_COMMAND_SET_GS,
  REMOTE_COMMAND_SET_DC,
  REMOTE_COMMAND_SET_ENABLE,
  REMOTE_COMMAND_RGB_CYCLE,
  REMOTE_COMMAND_RGB_PHASE_ROTATION,
  REMOTE_COMMAND_LED_CHASE,
  REMOTE_COMMAND_BRIGHTNESS_SWEEP,
  REMOTE_COMMAND_ALL_WHITE,
  REMOTE_COMMAND_ALL_OFF,
  REMOTE_COMMAND_STOP_TEST,
  REMOTE_COMMAND_PING,
  REMOTE_COMMAND_HELP
};

RemoteCommand pendingRemoteCommand =
  REMOTE_COMMAND_NONE;

char pendingRemoteCommandText[40] = "";


uint8_t pendingRemoteChannel = 0;
uint16_t pendingRemoteValue = 0;

bool mqttCommandStatusPublishPending = false;
bool mqttCapabilitiesPublishPending = true;

char mqttCommandStatusCommand[40] = "";
char mqttCommandStatusState[24] = "";
char mqttCommandStatusDetail[128] = "";

// ESP32 -> TLC6C5724 connections
#define PIN_MOSI   13   // TLC SDI, pin 1
#define PIN_MISO   27   // TLC SDO, pin 19
#define PIN_SCK    14   // TLC SCK, pin 2
#define PIN_LATCH  15   // TLC LATCH, pin 3
#define PIN_BLANK  4    // TLC BLANK, pin 36
#define PIN_GCLK   25   // TLC GCLK, pins 4/5/6
#define PIN_ERR    32   // TLC ERR, pin 20 (active-low, open-drain)

// Three physical TFT-menu buttons
#define PIN_BUTTON_PAGE    19
#define PIN_BUTTON_OPTION  21
#define PIN_BUTTON_SELECT  26

// TLC grayscale clock
constexpr uint32_t GCLK_FREQUENCY_HZ = 1000000;
constexpr uint8_t  GCLK_RESOLUTION_BITS = 5;
constexpr uint32_t GCLK_DUTY = 16;  // Approx. 50% of 0-31

// TFT pins are configured in TFT_eSPI/User_Setup.h
TFT_eSPI tft = TFT_eSPI();

// TLC common 288-bit shift-register frame
uint8_t frame[36];

// Readback buffer for SID and status data.
uint8_t sidFrame[36];

// Size of one 288-bit TLC frame.
constexpr size_t TLC_FRAME_BYTES = sizeof(sidFrame);

// Manual and remote channel state
constexpr uint8_t CHANNEL_COUNT = 24;

const char* const CHANNEL_NAMES[CHANNEL_COUNT] = {
  "R0", "G0", "B0", "R1", "G1", "B1",
  "R2", "G2", "B2", "R3", "G3", "B3",
  "R4", "G4", "B4", "R5", "G5", "B5",
  "R6", "G6", "B6", "R7", "G7", "B7"
};

// Startup pattern used for bench testing; other channels start at zero.
uint16_t gsValues[CHANNEL_COUNT] = {
  0xFFF, 0x000, 0x000,
  0x000, 0xFFF, 0x000,
  0x000, 0x000, 0xFFF,
  0x000, 0x000, 0x000,
  0x000, 0x000, 0x000,
  0x000, 0x000, 0x000,
  0x000, 0x000, 0x000,
  0x000, 0x000, 0x000
};

bool channelEnabled[CHANNEL_COUNT] = {
  true, true, true,
  true, true, true,
  true, true, true,
  false, false, false,
  false, false, false,
  false, false, false,
  false, false, false,
  false, false, false
};

uint8_t selectedChannel = 0;

// Preset grayscale levels used by the local controls.
constexpr uint16_t GS_LEVELS[] = {
  0x000,
  0x080,
  0x100,
  0x200,
  0x400,
  0x600,
  0x800,
  0xA00,
  0xC00,
  0xE00,
  0xFFF
};

constexpr size_t GS_LEVEL_COUNT =
  sizeof(GS_LEVELS) / sizeof(GS_LEVELS[0]);

// Per-channel 7-bit dot-correction values.
// Range: 0 ... 127
uint8_t dcValues[CHANNEL_COUNT] = {
  127, 127, 127, 127, 127, 127,
  127, 127, 127, 127, 127, 127,
  127, 127, 127, 127, 127, 127,
  127, 127, 127, 127, 127, 127
};

// Preset dot-correction levels.
constexpr uint8_t DC_LEVELS[] = {
  0,
  16,
  32,
  48,
  64,
  80,
  96,
  112,
  127
};

constexpr size_t DC_LEVEL_COUNT =
  sizeof(DC_LEVELS) / sizeof(DC_LEVELS[0]);

// Group brightness-control values.
// Index order: 0 = Red, 1 = Green, 2 = Blue
uint8_t bcValues[3] = {
  255,
  255,
  255
};

const char* const BC_GROUP_NAMES[3] = {
  "R",
  "G",
  "B"
};

// Preset group-brightness levels.
constexpr uint8_t BC_LEVELS[] = {
  0,
  32,
  64,
  96,
  128,
  160,
  192,
  224,
  255
};

constexpr size_t BC_LEVEL_COUNT =
  sizeof(BC_LEVELS) / sizeof(BC_LEVELS[0]);

// Temporary current profile used only for LOD/LSD diagnostics.
constexpr uint8_t DIAGNOSTIC_BC = 16;

// Three-button input
enum UiKey : uint8_t {
  KEY_NONE = 0,
  KEY_PAGE,
  KEY_OPTION,
  KEY_SELECT
};

struct ButtonState {
  uint8_t pin;
  UiKey key;
  uint8_t lastRawState;
  uint8_t stableState;
  uint32_t lastRawChangeTime;
};

constexpr uint32_t BUTTON_DEBOUNCE_MS = 35;

ButtonState buttons[] = {
  {PIN_BUTTON_PAGE,   KEY_PAGE,   HIGH, HIGH, 0},
  {PIN_BUTTON_OPTION, KEY_OPTION, HIGH, HIGH, 0},
  {PIN_BUTTON_SELECT, KEY_SELECT, HIGH, HIGH, 0}
};

constexpr size_t BUTTON_COUNT =
  sizeof(buttons) / sizeof(buttons[0]);

// TFT pages: Overview -> Manual -> Diagnostics -> Automatic Tests
enum UiPage : uint8_t {
  PAGE_OVERVIEW = 0,
  PAGE_MANUAL,
  PAGE_DIAGNOSTICS,
  PAGE_TESTS,
  PAGE_COUNT
};

UiPage currentPage = PAGE_OVERVIEW;
uint8_t selectedOption = 0;

constexpr uint8_t MANUAL_OPTION_COUNT = 5;
constexpr uint8_t TEST_OPTION_COUNT = 6;
constexpr uint8_t DIAGNOSTIC_OPTION_COUNT = 6;

// ERR is active-low:
// HIGH = no active fault
// LOW  = TLC is reporting a fault
bool lastErrActive = false;
bool errStatusInitialized = false;

constexpr uint32_t ERR_POLL_INTERVAL_MS = 100;
uint32_t previousErrPollTime = 0;

// Result decoded from LOD1, LOD2, LSD1 and LSD2
// for one selected TLC output.
enum LedDiagnosticStatus : uint8_t {
  LED_STATUS_OK = 0,
  LED_STATUS_OPEN,
  LED_STATUS_SHORT,
  LED_STATUS_OUTPUT_SHORT_GND,
  LED_STATUS_PWM_OR_UNKNOWN
};

constexpr uint8_t TLC_OUTPUT_COUNT = 24;

const char* const TLC_OUTPUT_NAMES[TLC_OUTPUT_COUNT] = {
  "R0", "G0", "B0", "R1", "G1", "B1",
  "R2", "G2", "B2", "R3", "G3", "B3",
  "R4", "G4", "B4", "R5", "G5", "B5",
  "R6", "G6", "B6", "R7", "G7", "B7"
};

// Channels populated on the current validation fixture.
const bool TLC_OUTPUT_CONNECTED[TLC_OUTPUT_COUNT] = {
  true, true, true, true, true, true,
  true, true, true, false, false, false,
  false, false, false, false, false, false,
  false, false, false, false, false, false
};

LedDiagnosticStatus allOutputStatus[TLC_OUTPUT_COUNT];

bool diagnosticsGridVisible = false;

uint8_t scanOpenCount = 0;
uint8_t scanShortCount = 0;
uint8_t scanGroundCount = 0;
uint8_t scanUnknownCount = 0;

// Adjacent-pin-short (APS) diagnostic result.
//   0b011 = pass
//   0b110 = adjacent-pin short detected
uint8_t apsFlag = 0;
bool apsOutputFault[TLC_OUTPUT_COUNT] = {false};
uint8_t apsFaultCount = 0;

// Global device-diagnostic flags read from SID.
bool deviceTefFlag = false;   // Thermal shutdown
bool devicePtwFlag = false;   // Pre-thermal warning
bool deviceIsfFlag = false;   // IREF short
bool deviceIofFlag = false;   // IREF open

// LOD/LSD detector-circuit self-test result from SID bits 208..206.
//   0b011 = self-test pass
//   0b110 = self-test fail
uint8_t lodLsdSelfTestFlag = 0;

// NEG/GCLK register-integrity diagnostic.
// The four LOD/LSD fields contain 96 relevant status bits in total.
constexpr uint16_t NEG_REGISTER_BIT_COUNT = 96;

constexpr uint16_t NEG_GCLK_WAIT_MS = 25;

bool negGclkTestPassed = false;
uint16_t negInversionMatchCount = 0;
uint16_t negConnectedInversionMatchCount = 0;


// Non-blocking automatic demonstration tests
enum AutomaticTest : uint8_t {
  AUTO_TEST_NONE = 0,
  AUTO_TEST_RGB_CYCLE,
  AUTO_TEST_RGB_PHASE_ROTATION,
  AUTO_TEST_LED_CHASE,
  AUTO_TEST_BRIGHTNESS_SWEEP,
  AUTO_TEST_ALL_WHITE,
  AUTO_TEST_ALL_OFF
};

AutomaticTest activeAutomaticTest = AUTO_TEST_NONE;

uint32_t previousAutomaticTestStepTime = 0;
uint8_t automaticTestStep = 0;
int8_t automaticBrightnessDirection = 1;

// Demo level for static RGB, chase, and white tests.
constexpr uint16_t DEMO_TEST_GS = 0x0800;

constexpr uint32_t RGB_CYCLE_STEP_MS = 650;
constexpr uint32_t RGB_PHASE_ROTATION_STEP_MS = 450;
constexpr uint32_t LED_CHASE_STEP_MS = 250;
constexpr uint32_t BRIGHTNESS_SWEEP_STEP_MS = 12;

// Function declarations

enum LedDiagnosticStatus : uint8_t;

// Wi-Fi and MQTT
void beginWifiConnection();
void beginWifiProfile(bool primaryProfile);
void configureMqttClient();
void configureMqttBrokerForCurrentWifi();
bool connectMqttBroker();
void serviceWifiAndMqtt();

void mqttMessageCallback(
  char* topic,
  uint8_t* payload,
  unsigned int length
);

RemoteCommand parseRemoteCommand(
  const char* commandText
);

const char* getRemoteCommandName(
  RemoteCommand command
);

void queueMqttCommandStatus(
  const char* command,
  const char* state,
  const char* detail
);

void publishMqttCommandStatus();
void publishMqttCapabilities();
void publishMqttChannelControl();
void publishMqttAutomaticTestStatus();

void queueMqttAutomaticTestStatus(
  const char* testName,
  const char* state
);

int8_t findChannelIndexByName(
  const char* channelName
);

void queueMqttChannelControlPublish(
  uint8_t channelIndex
);

void servicePendingRemoteCommand();

void runRemoteDiagnosticOption(
  uint8_t diagnosticOption
);

bool publishMqttMessage(
  const char* topic,
  const char* payload,
  bool retained
);

void publishMqttHeartbeat();
void publishMqttErrStatus();

const char* getMqttLedStatusCode(
  LedDiagnosticStatus status
);

void publishMqttChannelScan();
void publishMqttApsResult();
void publishMqttDeviceStatus();
void publishMqttLodLsdResult();
void publishMqttNegGclkResult();
void publishMqttErrorClearResult();

void queueMqttErrStatusPublish();
void queueMqttChannelScanPublish();
void queueMqttApsPublish();
void queueMqttDeviceStatusPublish();
void queueMqttLodLsdPublish();
void queueMqttNegGclkPublish();
void queueMqttErrorClearPublish(
  bool succeeded,
  bool errActive
);

void servicePendingDiagnosticPublishes();

// TLC frame helpers
void clearFrame();
void setBitTLC(uint16_t bit, bool value);
bool getBitTLC(uint16_t bit);
void setFieldTLC(uint16_t msb, uint16_t lsb, uint32_t value);

void clearSidFrame();
void setBufferBit(
  uint8_t* buffer,
  uint16_t bit,
  bool value
);
bool getBufferBit(
  const uint8_t* buffer,
  uint16_t bit
);

// TLC communication
void pulseSCK();
void pulseSCKFast();

void sendFCFrame();
void sendGSFrame();
void sendGSFrameFast();
void sendFCFrameFast();
void applyFcValuesFast();

void applyGsValuesFast();
void sendSpecialCommand(uint16_t command);
void readSidIntoBuffer();

// TLC configuration
void buildFCThreeRGB();
void buildGSThreeRGB();
void buildDiagnosticGsSingleOutput(uint8_t outputIndex);
void applyGsValues();
void applyFcValues();

void beginDiagnosticCurrentProfile(
  uint8_t savedBc[3]
);

void restoreDiagnosticCurrentProfile(
  const uint8_t savedBc[3]
);

const char* getSelectedChannelName();
uint8_t getSelectedBcGroup();
const char* getSelectedBcGroupName();
size_t findClosestGsLevel(uint16_t value);
size_t findClosestDcLevel(uint8_t value);
size_t findClosestBcLevel(uint8_t value);
void cycleSelectedManualValue();
void updateManualDynamicValues();
void updateManualValueField(
  int16_t y,
  uint8_t optionIndex,
  const char* value
);

// Physical buttons
void initializeButtons();
UiKey readUiButtons();
const char* getUiKeyName(UiKey key);

// UI helpers
uint8_t getOptionCount(UiPage page);
const char* getPageTitle(UiPage page);
void drawPageHeader();
void drawPageFooter();
void drawMenuRow(
  int16_t y,
  uint8_t optionIndex,
  const char* label,
  const char* value
);

// UI pages
void drawOverviewPage();
void drawManualPage();
void drawTestsPage();
void drawDiagnosticsPage();
void drawCurrentPage();

const char* getAutomaticTestName(
  AutomaticTest test
);

const char* getAutomaticTestLabel(
  AutomaticTest test
);

void showAutomaticTestMessage(
  const char* message,
  uint16_t color
);

void buildAutomaticRgbFrame(
  uint16_t red,
  uint16_t green,
  uint16_t blue
);

void buildAutomaticWhiteFrame(
  uint16_t level
);

void buildAutomaticPhaseRotationFrame(
  uint8_t phase,
  uint16_t level
);

void buildAutomaticChaseFrame(
  uint8_t ledIndex,
  uint8_t colourIndex,
  uint16_t level
);

void applyAutomaticTestFrame();
void renderAutomaticTestStep();

void startAutomaticTest(
  AutomaticTest test
);

void stopAutomaticTest(
  bool restoreManualState = true
);

void serviceAutomaticTest();
void runSelectedAutomaticTest();

void drawManualOption(uint8_t optionIndex);
void drawTestsOption(uint8_t optionIndex);
void drawDiagnosticsOption(uint8_t optionIndex);
void redrawCurrentPageOption(uint8_t optionIndex);

void drawDiagnosticsGrid();
void drawDiagnosticGridCell(
  uint8_t outputIndex,
  int16_t x,
  int16_t y
);

// Diagnostics
bool isErrActive();
void updateDiagnosticsErrStatus(bool forceRedraw = false);
void showDiagnosticsMessage(const char* message, uint16_t color);

void getOutputDiagnosticBits(
  uint8_t outputIndex,
  bool& lod1,
  bool& lod2,
  bool& lsd1,
  bool& lsd2
);

void getSelectedChannelDiagnosticBits(
  bool& lod1,
  bool& lod2,
  bool& lsd1,
  bool& lsd2
);

LedDiagnosticStatus classifyOutputSid(
  uint8_t outputIndex
);

LedDiagnosticStatus classifySelectedChannelSid();
const char* getLedDiagnosticStatusName(
  LedDiagnosticStatus status
);

LedDiagnosticStatus captureSelectedChannelSid();

void captureAllOutputSid();
void printAllOutputSid();

uint16_t getApsSidBit(uint8_t outputIndex);
void decodeApsResult();
void printApsResult();
void executeApsSpecialCommand(uint16_t command);
void runAdjacentPinTest();

void decodeDeviceStatusFlags();
void printDeviceStatusFlags();
void runDeviceStatusTest();

void decodeLodLsdSelfTestFlag();
void printLodLsdSelfTestResult();
void runLodLsdSelfTest();

bool isNegateControlledSidBit(uint16_t bit);
int8_t getNegateOutputIndexForSidBit(uint16_t bit);
const char* getNegateRegisterName(uint16_t bit);
bool isConnectedNegateSidBit(uint16_t bit);
uint16_t getConnectedNegateRegisterBitCount();

void buildNegGclkDiagnosticGsAllOutputs();

uint16_t countNegateInversionMatches(
  const uint8_t* beforeFrame,
  const uint8_t* afterFrame
);
uint16_t countConnectedNegateInversionMatches(
  const uint8_t* beforeFrame,
  const uint8_t* afterFrame
);
uint16_t countNegateEqualityMatches(
  const uint8_t* firstFrame,
  const uint8_t* secondFrame
);
uint16_t countConnectedNegateEqualityMatches(
  const uint8_t* firstFrame,
  const uint8_t* secondFrame
);

void printNegateMismatchedBits(
  const uint8_t* beforeFrame,
  const uint8_t* afterFrame
);
void printIgnoredNcNegateMismatches(
  const uint8_t* beforeFrame,
  const uint8_t* afterFrame
);

void runNegGclkIntegrityTest();

uint8_t getSidFieldByte(uint16_t msb);
void printByteBinary(uint8_t value);
void printSidRawFrame();
void printSidGroupFields();
void printSidBitWindow(
  const char* label,
  uint16_t centerBit
);
void runSidRawDebugForOutput(uint8_t outputIndex);
void runSidRawDebug();

void printSelectedChannelSid(
  LedDiagnosticStatus status
);

void runSelectedDiagnostic();

// UI navigation
void changePage(int8_t direction);
void changeOption(int8_t direction);
void activateSelectedOption();

void setup() {
  Serial.begin(115200);
  delay(800);

  // TLC pins
  pinMode(PIN_MOSI, OUTPUT);
  pinMode(PIN_MISO, INPUT);
  pinMode(PIN_SCK, OUTPUT);
  pinMode(PIN_LATCH, OUTPUT);
  pinMode(PIN_BLANK, OUTPUT);
  pinMode(PIN_GCLK, OUTPUT);
  pinMode(PIN_ERR, INPUT);  // External 9-10 kOhm pull-up to 3.3 V

  // Local controls
  initializeButtons();

  // Safe startup levels
  digitalWrite(PIN_MOSI, LOW);
  digitalWrite(PIN_SCK, LOW);
  digitalWrite(PIN_LATCH, HIGH);
  digitalWrite(PIN_BLANK, LOW);
  digitalWrite(PIN_GCLK, LOW);

  Serial.println();
  Serial.println("Starting TLC6C5724 + TFT menu system");

  // Display
  tft.init();
  tft.setRotation(1);  // 160 x 128 landscape
  tft.setTextWrap(false);
  drawCurrentPage();

  // Reset and initialize the TLC driver.
  executeApsSpecialCommand(0xA5C);  // Global reset
  delay(20);

  executeApsSpecialCommand(0xA53);  // Clear errors
  delay(20);

  buildFCThreeRGB();
  sendFCFrame();
  delay(20);

  buildGSThreeRGB();
  sendGSFrame();
  delay(20);

  // Start the TLC grayscale clock.
  if (!ledcAttach(
        PIN_GCLK,
        GCLK_FREQUENCY_HZ,
        GCLK_RESOLUTION_BITS)) {

    Serial.println("ERROR: GCLK hardware PWM setup failed.");
    digitalWrite(PIN_BLANK, LOW);

    while (true) {
      delay(1000);
    }
  }

  ledcWrite(PIN_GCLK, GCLK_DUTY);
  delayMicroseconds(100);

  // Enable outputs after GCLK is stable.
  digitalWrite(PIN_BLANK, HIGH);

  lastErrActive = isErrActive();
  errStatusInitialized = true;
  previousErrPollTime = millis();

  Serial.print("Initial ERR pin state: ");
  Serial.println(
    lastErrActive ? "LOW - ACTIVE" : "HIGH - OK"
  );

  Serial.println("Display and TLC driver ready.");
  Serial.println("Local diagnostics and LED controls ready.");

  configureMqttClient();
  beginWifiConnection();

  Serial.println("MQTT remote control enabled.");
  Serial.println("Buttons: PAGE, OPTION, SELECT.");
}


void loop() {
  const UiKey key = readUiButtons();

  if (key != KEY_NONE) {
    Serial.print("Detected key: ");
    Serial.println(getUiKeyName(key));
  }

  switch (key) {
    case KEY_PAGE:
      changePage(1);
      break;

    case KEY_OPTION:
      changeOption(1);
      break;

    case KEY_SELECT:
      activateSelectedOption();
      break;

    case KEY_NONE:
    default:
      break;
  }

  const uint32_t now = millis();

  if (now - previousErrPollTime >= ERR_POLL_INTERVAL_MS) {
    previousErrPollTime = now;
    updateDiagnosticsErrStatus(false);
  }

  // Give local button input priority over queued remote commands.
  if (key == KEY_NONE) {
    servicePendingRemoteCommand();
  }

  // Automatic tests remain non-blocking.
  serviceAutomaticTest();

  serviceWifiAndMqtt();

  delay(5);
}

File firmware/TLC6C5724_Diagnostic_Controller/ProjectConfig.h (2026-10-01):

#pragma once

#include <Arduino.h>

// Network credentials are kept outside the sketch.
// Copy Secrets.example.h to Secrets.h and fill in your local values.
#if defined(__has_include)
  #if __has_include("Secrets.h")
    #include "Secrets.h"
  #endif
#endif

#ifndef WIFI_FALLBACK_SSID_VALUE
  #define WIFI_FALLBACK_SSID_VALUE ""
#endif
#ifndef WIFI_FALLBACK_PASSWORD_VALUE
  #define WIFI_FALLBACK_PASSWORD_VALUE ""
#endif
#ifndef WIFI_PRIMARY_SSID_VALUE
  #define WIFI_PRIMARY_SSID_VALUE ""
#endif
#ifndef WIFI_PRIMARY_PASSWORD_VALUE
  #define WIFI_PRIMARY_PASSWORD_VALUE ""
#endif
#ifndef MQTT_FALLBACK_BROKER_VALUE
  #define MQTT_FALLBACK_BROKER_VALUE ""
#endif
#ifndef MQTT_USERNAME_VALUE
  #define MQTT_USERNAME_VALUE ""
#endif
#ifndef MQTT_PASSWORD_VALUE
  #define MQTT_PASSWORD_VALUE ""
#endif

static const char WIFI_FALLBACK_SSID[] = WIFI_FALLBACK_SSID_VALUE;
static const char WIFI_FALLBACK_PASSWORD[] = WIFI_FALLBACK_PASSWORD_VALUE;
static const char WIFI_PRIMARY_SSID[] = WIFI_PRIMARY_SSID_VALUE;
static const char WIFI_PRIMARY_PASSWORD[] = WIFI_PRIMARY_PASSWORD_VALUE;

static const char MQTT_FALLBACK_BROKER[] = MQTT_FALLBACK_BROKER_VALUE;
static const char MQTT_USERNAME[] = MQTT_USERNAME_VALUE;
static const char MQTT_PASSWORD[] = MQTT_PASSWORD_VALUE;

constexpr uint16_t MQTT_PORT = 1883;

static const char MQTT_DEVICE_ID[] = "tlc6c5724-device01";

static const char MQTT_TOPIC_AVAILABILITY[] = "tlc6c5724/device01/availability";
static const char MQTT_TOPIC_HEARTBEAT[] = "tlc6c5724/device01/heartbeat";
static const char MQTT_TOPIC_ERR[] = "tlc6c5724/device01/err";
static const char MQTT_TOPIC_CHANNEL_SCAN[] = "tlc6c5724/device01/channel-scan";
static const char MQTT_TOPIC_APS[] = "tlc6c5724/device01/aps";
static const char MQTT_TOPIC_DEVICE_STATUS[] = "tlc6c5724/device01/device-status";
static const char MQTT_TOPIC_LOD_LSD_SELF_TEST[] = "tlc6c5724/device01/lod-lsd-self-test";
static const char MQTT_TOPIC_NEG_GCLK[] = "tlc6c5724/device01/neg-gclk";
static const char MQTT_TOPIC_ERROR_CLEAR[] = "tlc6c5724/device01/error-clear";
static const char MQTT_TOPIC_COMMAND[] = "tlc6c5724/device01/command";
static const char MQTT_TOPIC_COMMAND_STATUS[] = "tlc6c5724/device01/command-status";
static const char MQTT_TOPIC_CAPABILITIES[] = "tlc6c5724/device01/capabilities";
static const char MQTT_TOPIC_CHANNEL_CONTROL[] = "tlc6c5724/device01/channel-control";
static const char MQTT_TOPIC_AUTOMATIC_TEST[] = "tlc6c5724/device01/automatic-test";

constexpr uint32_t WIFI_PROFILE_RECOVERY_MS = 12000;
constexpr uint32_t WIFI_RETRY_INTERVAL_MS = 10000;
constexpr uint32_t MQTT_RETRY_INTERVAL_MS = 5000;
constexpr uint32_t MQTT_HEARTBEAT_INTERVAL_MS = 30000;

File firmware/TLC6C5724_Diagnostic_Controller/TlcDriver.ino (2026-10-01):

void clearFrame() {
  memset(frame, 0, sizeof(frame));
}

// TLC bit 287 -> frame[0], bit 7
// TLC bit   0 -> frame[35], bit 0
void setBitTLC(uint16_t bit, bool value) {
  if (bit > 287) {
    return;
  }

  const uint16_t serialPosition = 287 - bit;
  const uint8_t byteIndex = serialPosition / 8;
  const uint8_t bitIndex = 7 - (serialPosition % 8);

  if (value) {
    frame[byteIndex] |= (1U << bitIndex);
  } else {
    frame[byteIndex] &= ~(1U << bitIndex);
  }
}

bool getBitTLC(uint16_t bit) {
  if (bit > 287) {
    return false;
  }

  const uint16_t serialPosition = 287 - bit;
  const uint8_t byteIndex = serialPosition / 8;
  const uint8_t bitIndex = 7 - (serialPosition % 8);

  return (frame[byteIndex] >> bitIndex) & 0x01;
}

void setFieldTLC(uint16_t msb, uint16_t lsb, uint32_t value) {
  if (msb < lsb || msb > 287) {
    return;
  }

  for (uint16_t i = 0; i <= (msb - lsb); i++) {
    setBitTLC(lsb + i, (value >> i) & 0x01);
  }
}

void clearSidFrame() {
  memset(sidFrame, 0, sizeof(sidFrame));
}

void setBufferBit(
  uint8_t* buffer,
  uint16_t bit,
  bool value
) {
  if (buffer == nullptr || bit > 287) {
    return;
  }

  const uint16_t serialPosition = 287 - bit;
  const uint8_t byteIndex = serialPosition / 8;
  const uint8_t bitIndex = 7 - (serialPosition % 8);

  if (value) {
    buffer[byteIndex] |= (1U << bitIndex);
  } else {
    buffer[byteIndex] &= ~(1U << bitIndex);
  }
}

bool getBufferBit(
  const uint8_t* buffer,
  uint16_t bit
) {
  if (buffer == nullptr || bit > 287) {
    return false;
  }

  const uint16_t serialPosition = 287 - bit;
  const uint8_t byteIndex = serialPosition / 8;
  const uint8_t bitIndex = 7 - (serialPosition % 8);

  return (buffer[byteIndex] >> bitIndex) & 0x01;
}


void pulseSCK() {
  digitalWrite(PIN_SCK, HIGH);
  delayMicroseconds(10);

  digitalWrite(PIN_SCK, LOW);
  delayMicroseconds(10);
}

void pulseSCKFast() {
  digitalWrite(PIN_SCK, HIGH);
  delayMicroseconds(1);

  digitalWrite(PIN_SCK, LOW);
  delayMicroseconds(1);
}
void sendFCFrame() {
  digitalWrite(PIN_BLANK, LOW);
  digitalWrite(PIN_SCK, LOW);
  digitalWrite(PIN_MOSI, LOW);

  // LATCH is normally already HIGH because sendGSFrame()
  // now leaves it in the safe idle state. Therefore this line
  // does not create an unintended rising edge before shifting.
  digitalWrite(PIN_LATCH, HIGH);
  delayMicroseconds(20);

  for (int bit = 287; bit >= 0; bit--) {
    digitalWrite(PIN_MOSI, getBitTLC(bit) ? HIGH : LOW);
    delayMicroseconds(10);
    pulseSCK();
  }

  delayMicroseconds(20);

  digitalWrite(PIN_LATCH, LOW);
  delayMicroseconds(20);

  digitalWrite(PIN_LATCH, HIGH);
  delayMicroseconds(20);

  digitalWrite(PIN_MOSI, LOW);
  delayMicroseconds(100);
}

void sendFCFrameFast() {
  digitalWrite(PIN_BLANK, LOW);
  digitalWrite(PIN_SCK, LOW);
  digitalWrite(PIN_MOSI, LOW);

  // FC/BC/DC frame requires LATCH HIGH on the 288th SCK edge.
  digitalWrite(PIN_LATCH, HIGH);
  delayMicroseconds(1);

  for (int bit = 287; bit >= 0; bit--) {
    digitalWrite(
      PIN_MOSI,
      getBitTLC(bit) ? HIGH : LOW
    );

    delayMicroseconds(1);
    pulseSCKFast();
  }

  delayMicroseconds(1);

  // Transfer completed FC/BC/DC frame.
  digitalWrite(PIN_LATCH, LOW);
  delayMicroseconds(1);

  digitalWrite(PIN_LATCH, HIGH);
  delayMicroseconds(1);

  digitalWrite(PIN_MOSI, LOW);
}

void sendGSFrame() {
  digitalWrite(PIN_BLANK, LOW);
  digitalWrite(PIN_SCK, LOW);

  // LATCH must be LOW at the 288th SCK rising edge so the
  // 288-bit common register is interpreted as GS data.
  digitalWrite(PIN_LATCH, LOW);
  delayMicroseconds(20);

  for (int bit = 287; bit >= 0; bit--) {
    digitalWrite(PIN_MOSI, getBitTLC(bit) ? HIGH : LOW);
    delayMicroseconds(10);
    pulseSCK();
  }

  delayMicroseconds(20);

  // Rising edge transfers the completed frame into the GS latch.
  digitalWrite(PIN_LATCH, HIGH);
  delayMicroseconds(100);

  // IMPORTANT:
  // Leave LATCH HIGH as the idle state.
  //
  // After a GS write, the TLC loads FC/BC/DC data back into the
  // common shift register. If we ended this function with LATCH LOW,
  // the next sendFCFrame() would begin by raising LATCH and could
  // unintentionally latch that common-register content into GS again.
}

void sendGSFrameFast() {
  digitalWrite(PIN_BLANK, LOW);
  digitalWrite(PIN_SCK, LOW);

  // LOW during the 288th SCK rising edge = GS frame.
  digitalWrite(PIN_LATCH, LOW);
  delayMicroseconds(1);

  for (int bit = 287; bit >= 0; bit--) {
    digitalWrite(PIN_MOSI, getBitTLC(bit) ? HIGH : LOW);

    delayMicroseconds(1);
    pulseSCKFast();
  }

  delayMicroseconds(1);

  // Rising edge transfers the completed frame into GS latch.
  digitalWrite(PIN_LATCH, HIGH);
  delayMicroseconds(1);

  // Return data line to a defined idle state.
  digitalWrite(PIN_MOSI, LOW);

  // Keep LATCH HIGH, same as our validated sendGSFrame().
}
void sendSpecialCommand(uint16_t command) {
  clearFrame();
  setFieldTLC(287, 276, command & 0x0FFF);

  digitalWrite(PIN_BLANK, LOW);
  digitalWrite(PIN_SCK, LOW);
  digitalWrite(PIN_LATCH, LOW);

  for (int bit = 287; bit >= 0; bit--) {
    digitalWrite(PIN_MOSI, getBitTLC(bit) ? HIGH : LOW);
    delayMicroseconds(10);

    if (bit == 0) {
      digitalWrite(PIN_LATCH, HIGH);
      delayMicroseconds(20);
    }

    pulseSCK();

    if (bit == 0) {
      delayMicroseconds(20);
      digitalWrite(PIN_LATCH, LOW);
    }
  }

  delayMicroseconds(100);
}

void readSidIntoBuffer() {
  clearSidFrame();

  // 0x5A3 loads SID into the common 288-bit shift register.
  sendSpecialCommand(0x5A3);

  // The command function finishes LOW. This rising edge ensures
  // that the command is executed and leaves LATCH stable during
  // the following 288 read clocks.
  digitalWrite(PIN_LATCH, HIGH);
  delayMicroseconds(20);

  digitalWrite(PIN_SCK, LOW);
  digitalWrite(PIN_MOSI, LOW);

  // The register MSB, TLC bit 287, is already present on SDO
  // before the first read clock. Sample first, then shift.
  for (int bit = 287; bit >= 0; bit--) {
    delayMicroseconds(2);

    const bool value =
      digitalRead(PIN_MISO) == HIGH;

    setBufferBit(
      sidFrame,
      static_cast<uint16_t>(bit),
      value
    );

    pulseSCK();
  }

  digitalWrite(PIN_LATCH, HIGH);
  delayMicroseconds(20);

  // sendSpecialCommand() drives BLANK LOW.
  // Always re-enable the TLC outputs after the SID frame
  // has been completely shifted into sidFrame.
  digitalWrite(PIN_BLANK, HIGH);
}
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

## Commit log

2026-10-01 Initial commit: TLC6C5724-Q1 automotive RGB lighting diagnostic platform
    ESP32 firmware (driver, diagnostics, auto tests, TFT UI, MQTT), Node-RED
    Dashboard 2 flow, KiCad schematics and README with figures from the
    project report. Credentials live in a git-ignored Secrets.h.
    [TLC_breakout.kicad_sch, tlc6c5724-esp32-prototype.kicad_sch]
2026-10-01 Add TLC6C5724-Q1 breakout board PCB layout (KiCad)
    [TLC_breakout.kicad_pcb]
2026-10-01 Add Mosquitto demo config, launcher script and schematic PDF
